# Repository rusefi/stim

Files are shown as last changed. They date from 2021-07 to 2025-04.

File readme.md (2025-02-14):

[Interactive Pinout](https://rusefi.com/docs/pinouts/stim/)

## User Manual

* 12v DC power required
* one microUSB cable required for operation
* sometimes second microUSB is useful for firmware update

WhatsApp Image 2024-11-09 at 19 40 01_332a49eb





* [Download Putty](https://www.chiark.greenend.org.uk/~sgtatham/putty/latest.html)
* bottom microUSB is required for operation
* top microUSB is sometimes needed for firmware updates
* blinking blue LD2 means "alive"
* red LD3 means "board has failed test
* green LD1 next to blinking blue means "test successful"

See https://github.com/rusefi/rusefi-hardware/tree/main/digital-inputs for firmware

Part of https://github.com/rusefi/rusefi infrastucture

https://github.com/rusefi/rusefi/wiki/dev-hardware-quality-control



# Digital Inputs
- 48 channels of high/low digital inputs
- pin requirment: 4 ADC inputs and 9 GPIO

GPIO:
* output: x4 address pins
* output: x4 test control pins
* output: mux off

See https://github.com/rusefi/stim/issues/6

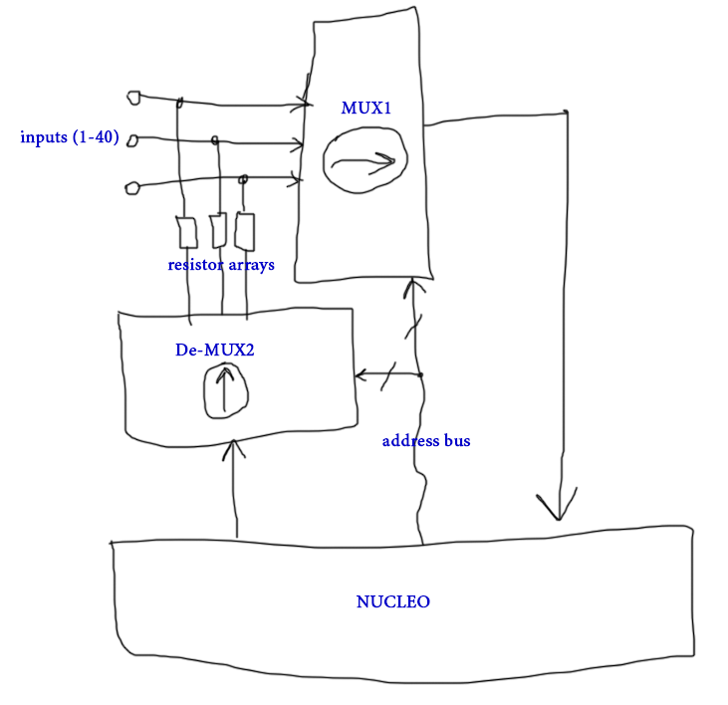
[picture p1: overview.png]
x


# Changelog

## rev C

* CAN board fix
* second CAN board added
* OUT0 pin moved from PA11 to PD8
* https://github.com/rusefi/stim/issues?q=label%3Arev-C+is%3Aclosed

## rev 0.2

* CAN bus
* superseal header

##  rev 0.1
* it works!

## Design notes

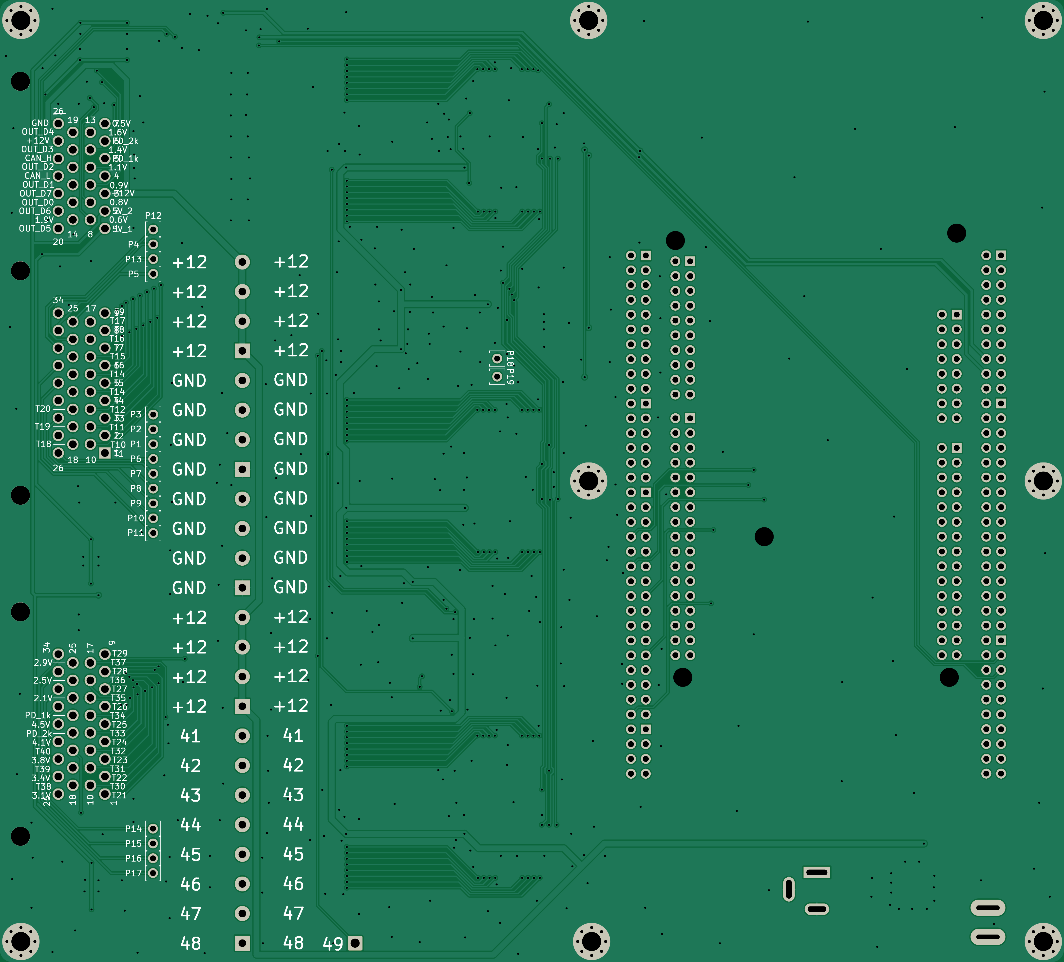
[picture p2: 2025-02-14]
boards/digital_inputs-e/board/misc/digital_inputs-e-bottom.png

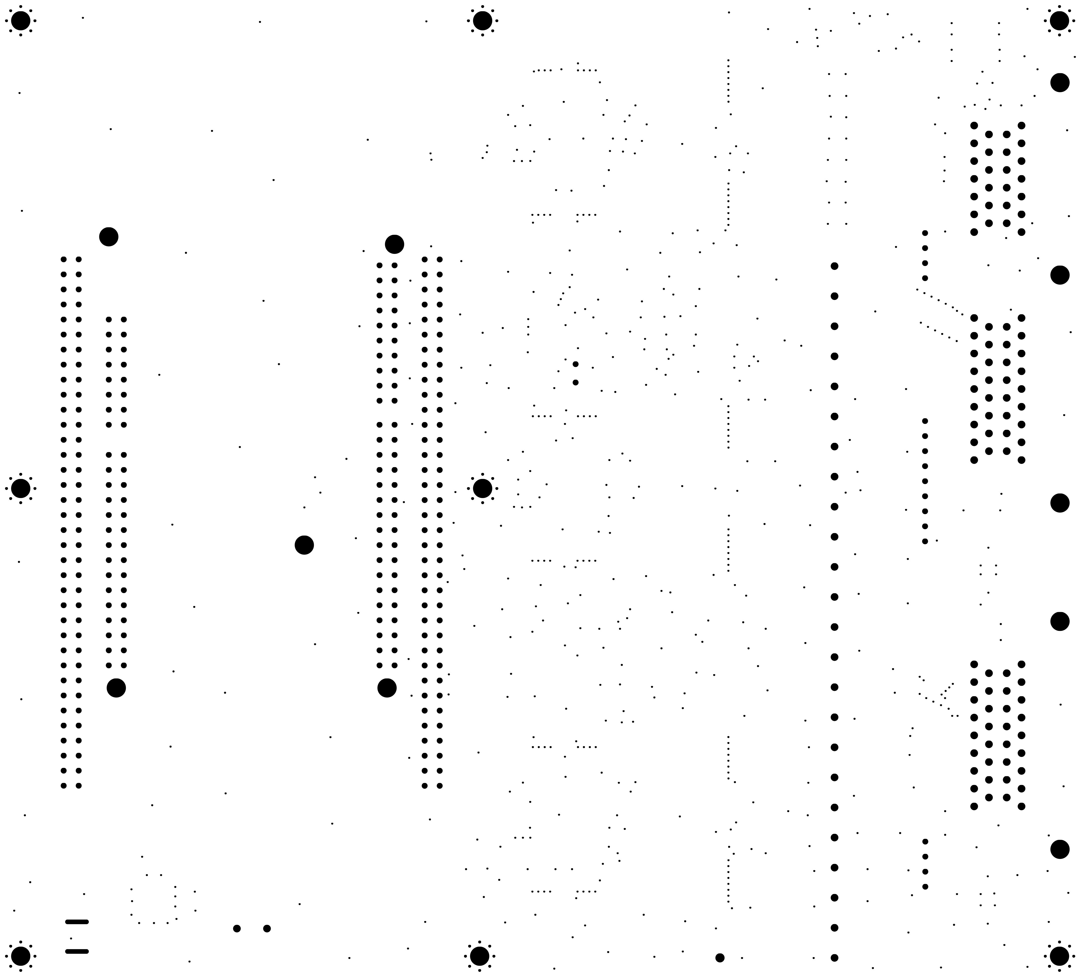
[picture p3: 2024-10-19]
boards/digital_inputs-d/board/misc/digital_inputs-d-outline.png

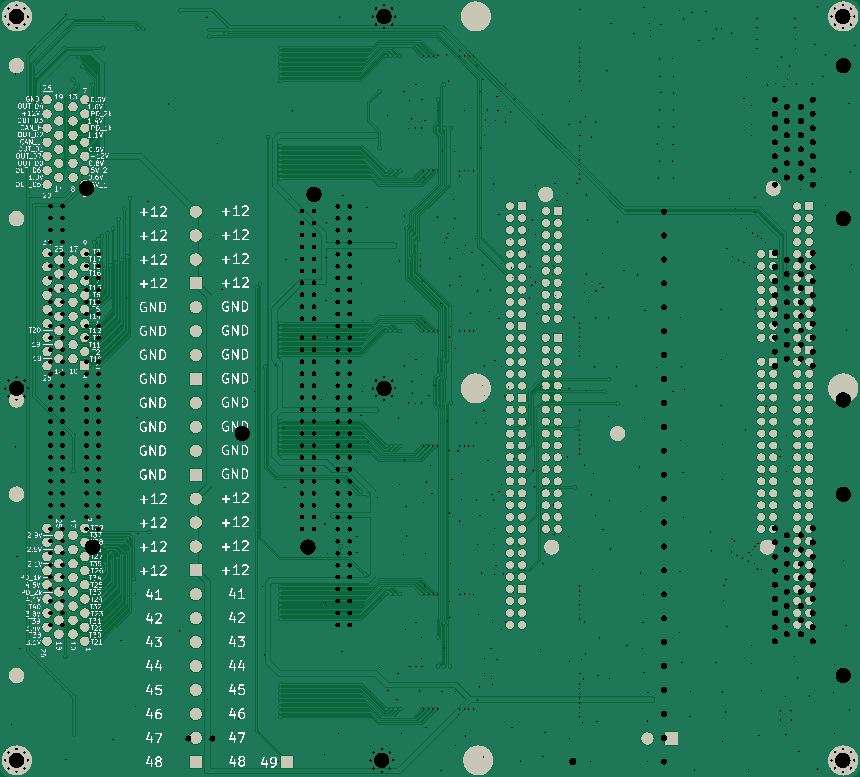
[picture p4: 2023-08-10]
boards/digital_inputs-a/board/misc/digital_inputs-a-bottom.png

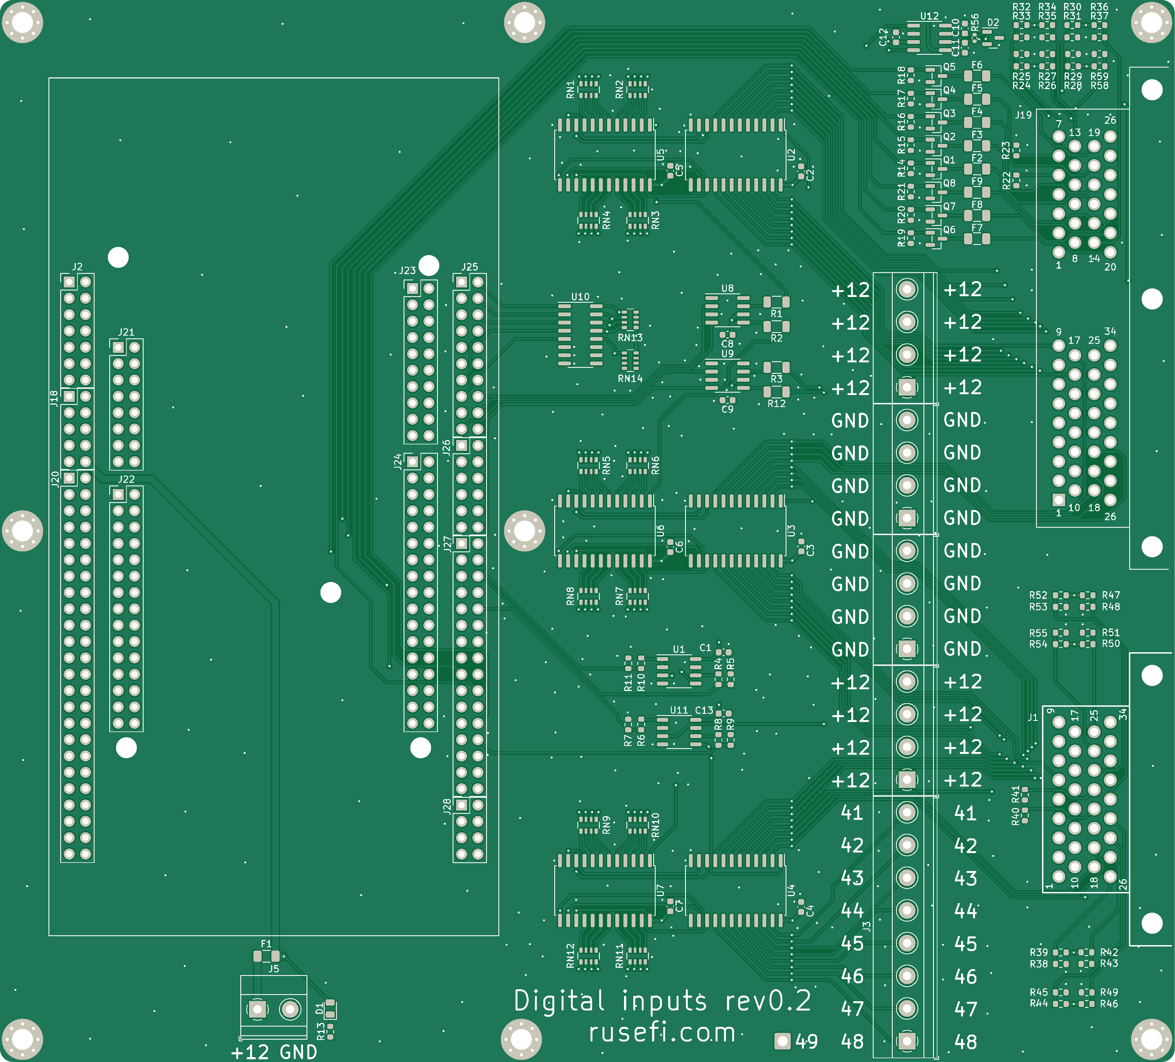
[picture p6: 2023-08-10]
boards/digital_inputs-a/board/digital_inputs-a.png

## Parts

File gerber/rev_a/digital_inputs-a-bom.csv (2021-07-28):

Comment | Designator | Footprint | LCSC Part #
100n | C1 | Capacitor_SMD:C_0603_1608Metric | C14663
100n | C2 | Capacitor_SMD:C_0603_1608Metric | C14663
100n | C3 | Capacitor_SMD:C_0603_1608Metric | C14663
100n | C4 | Capacitor_SMD:C_0603_1608Metric | C14663
100n | C5 | Capacitor_SMD:C_0603_1608Metric | C14663
100n | C6 | Capacitor_SMD:C_0603_1608Metric | C14663
100n | C7 | Capacitor_SMD:C_0603_1608Metric | C14663
100n | C8 | Capacitor_SMD:C_0603_1608Metric | C14663
100n | C9 | Capacitor_SMD:C_0603_1608Metric | C14663
LED | D1 | LED_SMD:LED_0805_2012Metric | C2297
1.8A | F1 | Fuse:Fuse_1206_3216Metric | C369161
Conn_01x16 | J1 | TerminalBlock_Phoenix:TerminalBlock_Phoenix_MKDS-1,5-16-5.08_1x16_P5.08mm_Horizontal
Conn_01x16 | J2 | TerminalBlock_Phoenix:TerminalBlock_Phoenix_MKDS-1,5-16-5.08_1x16_P5.08mm_Horizontal
Conn_01x16 | J3 | TerminalBlock_Phoenix:TerminalBlock_Phoenix_MKDS-1,5-16-5.08_1x16_P5.08mm_Horizontal
Conn_01x01 | J4 | Connector_Wire:SolderWire-0.75sqmm_1x01_D1.25mm_OD2.3mm
Conn_01x02 | J5 | TerminalBlock_Phoenix:TerminalBlock_Phoenix_MKDS-1,5-2-5.08_1x02_P5.08mm_Horizontal
Conn_01x04 | J6 | TerminalBlock_Phoenix:TerminalBlock_Phoenix_MKDS-1,5-4-5.08_1x04_P5.08mm_Horizontal
Conn_01x04 | J7 | TerminalBlock_Phoenix:TerminalBlock_Phoenix_MKDS-1,5-4-5.08_1x04_P5.08mm_Horizontal
Conn_01x04 | J8 | TerminalBlock_Phoenix:TerminalBlock_Phoenix_MKDS-1,5-4-5.08_1x04_P5.08mm_Horizontal
Conn_01x04 | J9 | TerminalBlock_Phoenix:TerminalBlock_Phoenix_MKDS-1,5-4-5.08_1x04_P5.08mm_Horizontal
Conn_01x01 | J10 | MountingHole:MountingHole_3.2mm_M3_Pad_Via
Conn_01x01 | J11 | MountingHole:MountingHole_3.2mm_M3_Pad_Via
Conn_01x01 | J12 | MountingHole:MountingHole_3.2mm_M3_Pad_Via
Conn_01x01 | J13 | MountingHole:MountingHole_3.2mm_M3_Pad_Via
Conn_01x01 | J14 | MountingHole:MountingHole_3.2mm_M3_Pad_Via
Conn_01x01 | J15 | MountingHole:MountingHole_3.2mm_M3_Pad_Via
Conn_01x01 | J16 | MountingHole:MountingHole_3.2mm_M3_Pad_Via
Conn_01x01 | J17 | MountingHole:MountingHole_3.2mm_M3_Pad_Via
1.2k | R1 | Resistor_SMD:R_1206_3216Metric | C26035
1.2k | R2 | Resistor_SMD:R_1206_3216Metric | C26035
1.2k | R3 | Resistor_SMD:R_1206_3216Metric | C26035
4.7k | R4 | Resistor_SMD:R_0603_1608Metric | C23162
1.5k | R5 | Resistor_SMD:R_0603_1608Metric | C22843
4.7k | R6 | Resistor_SMD:R_0603_1608Metric | C23162
1.5k | R7 | Resistor_SMD:R_0603_1608Metric | C22843
4.7k | R8 | Resistor_SMD:R_0603_1608Metric | C23162
1.5k | R9 | Resistor_SMD:R_0603_1608Metric | C22843
4.7k | R10 | Resistor_SMD:R_0603_1608Metric | C23162
1.5k | R11 | Resistor_SMD:R_0603_1608Metric | C22843
1.2k | R12 | Resistor_SMD:R_1206_3216Metric | C26035
4.7k | R13 | Resistor_SMD:R_0603_1608Metric | C23162
0 | RN1 | Resistor_SMD:R_Array_Convex_4x0603 | C327053
0 | RN2 | Resistor_SMD:R_Array_Convex_4x0603 | C327053
0 | RN3 | Resistor_SMD:R_Array_Convex_4x0603 | C327053
0 | RN4 | Resistor_SMD:R_Array_Convex_4x0603 | C327053
0 | RN5 | Resistor_SMD:R_Array_Convex_4x0603 | C327053
0 | RN6 | Resistor_SMD:R_Array_Convex_4x0603 | C327053
0 | RN7 | Resistor_SMD:R_Array_Convex_4x0603 | C327053
0 | RN8 | Resistor_SMD:R_Array_Convex_4x0603 | C327053
0 | RN9 | Resistor_SMD:R_Array_Convex_4x0603 | C327053
0 | RN10 | Resistor_SMD:R_Array_Convex_4x0603 | C327053
0 | RN11 | Resistor_SMD:R_Array_Convex_4x0603 | C327053
0 | RN12 | Resistor_SMD:R_Array_Convex_4x0603 | C327053
10k | RN13 | Resistor_SMD:R_Array_Convex_4x0603 | C29718
10k | RN14 | Resistor_SMD:R_Array_Convex_4x0603 | C29718
OPA4192IPW | U1 | Package_SO:TSSOP-14_4.4x5mm_P0.65mm | C181634
CD4067BM96 | U2 | Package_SO:SOIC-24W_7.5x15.4mm_P1.27mm | C6525
CD4067BM96 | U3 | Package_SO:SOIC-24W_7.5x15.4mm_P1.27mm | C6525
CD4067BM96 | U4 | Package_SO:SOIC-24W_7.5x15.4mm_P1.27mm | C6525
CD4067BM96 | U5 | Package_SO:SOIC-24W_7.5x15.4mm_P1.27mm | C6525
CD4067BM96 | U6 | Package_SO:SOIC-24W_7.5x15.4mm_P1.27mm | C6525
CD4067BM96 | U7 | Package_SO:SOIC-24W_7.5x15.4mm_P1.27mm | C6525
TC4427 | U8 | Package_SO:SOIC-8_3.9x4.9mm_P1.27mm | C20551
TC4427 | U9 | Package_SO:SOIC-8_3.9x4.9mm_P1.27mm | C20551
ULN2003A | U10 | Package_SO:SOIC-16_3.9x9.9mm_P1.27mm | C7512
NUCLEO-F429ZI | U11 | lib:MODULE_NUCLEO-F429ZI

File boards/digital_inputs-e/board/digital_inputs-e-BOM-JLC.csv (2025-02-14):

Comment | Designator | Footprint | LCSC Part #
100n | C1, C2, C3, C4, C5, C6, C7, C8, C9, C12, C13, C16 | C0603 | C14663
47p | C10, C11, C14, C15 | C0603 | C1671
10u | C17, C18 | C0805 | C15850
CircuitBreaker_1P | CB1 | RS601HL-1010011BB | C2885782
LED | D1 | LED_0805_2012Metric | C2297
PESD1CAN | D2, D6 | SOT-23 | C343993
LED-RED-0603 | D3, D4 | LED-0603 | C2286
Barrel_Jack_Switch | J2 | BarrelJack_GCT_DCJ200-10-A_Horizontal | C111567
6437288-3 | J19 | TE_6437288-3 | C591769
Conn_02x10_Odd_Even | J20, J25, J29 | PinHeader_2x10_P2.54mm_Vertical | C92266
Conn_02x16_Odd_Even | J27 | PinHeader_2x16_P2.54mm_Vertical | C132130
AO3400A | Q1, Q2, Q3, Q4, Q5, Q6, Q7, Q8 | SOT-23 | C20917
1.2k | R1, R2, R3, R12 | R1206 | C26035
4.7k | R4, R6, R8, R10, R14, R15, R16, R17, R18, R19, R20, R21, R57, R60 | R0603 | C23162
1.5k | R5, R7, R9, R11 | R0603 | C22843
13k | R13 | R0603 | C22797
1k | R22, R40 | R0603 | C21190
2k | R23, R41 | R0603 | C4190
820 | R24, R26, R30, R32, R36, R39, R49 | R0603 | C23253
100 | R25, R29, R44, R46, R47, R59 | R0603 | C22775
120 | R27 | R0603 | C22787
470 | R28, R34, R43, R51, R52, R54, R55 | R0603 | C23179
220 | R31, R35, R42 | R0603 | C22962
330 | R33, R45, R50, R53 | R0603 | C23138
510 | R37, R38, R58 | R0603 | C23193
910 | R48 | R0603 | C23264
0 | RN1, RN2, RN3, RN4, RN5, RN6, RN7, RN8, RN9, RN10, RN11, RN12 | R_Array_Convex_4x0603 | C327053
10k | RN13, RN14 | R_Array_Convex_4x0603 | C29718
OPA2192IDR | U1, U11 | SO-8_3.9x4.9mm_P1.27mm | C110074
CD4067BM96 | U2, U3, U4, U5, U6, U7 | SOIC-24W_7.5x15.4mm_P1.27mm | C6525
TC4427 | U8, U9 | SO8 | C20551
ULN2003A | U10 | SOIC-16_3.9x9.9mm_P1.27mm | C7512
TJA1051T-3 | U12, U13 | SO8 | C38695
LM78M05_TO252 | U14 | DPAK | C58069
nSMD005 | F2, F3, F4, F5, F6, F7, F8, F9 | F1206 | C70064
nSMD100-16 | F1 | F1206 | C70082

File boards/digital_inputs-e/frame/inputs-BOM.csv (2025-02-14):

Comment | Designator | Footprint | LCSC Part #
100n | C1 | C0603 | C14663
100n | C2 | C0603 | C14663
100n | C3 | C0603 | C14663
100n | C4 | C0603 | C14663
100n | C5 | C0603 | C14663
100n | C6 | C0603 | C14663
100n | C7 | C0603 | C14663
100n | C8 | C0603 | C14663
100n | C9 | C0603 | C14663
47p | C10 | C0603 | C1671
47p | C11 | C0603 | C1671
100n | C12 | C0603 | C14663
100n | C13 | C0603 | C14663
47p | C14 | C0603 | C1671
47p | C15 | C0603 | C1671
100n | C16 | C0603 | C14663
10u | C17 | C0805 | C15850
10u | C18 | C0805 | C15850
CircuitBreaker_1P | CB1 | RS601HL-1010011BB | C2885782
LED | D1 | LED_0805_2012Metric | C2297
PESD1CAN | D2 | SOT-23 | C343993
LED-RED-0603 | D3 | LED-0603 | C2286
LED-RED-0603 | D4 | LED-0603 | C2286
PESD1CAN | D6 | SOT-23 | C343993
1.8A | F1 | Fuse_1206_3216Metric | C369161
nSMD005 | F2 | Fuse_1206_3216Metric | C369153
nSMD005 | F3 | Fuse_1206_3216Metric | C369153
nSMD005 | F4 | Fuse_1206_3216Metric | C369153
nSMD005 | F5 | Fuse_1206_3216Metric | C369153
nSMD005 | F6 | Fuse_1206_3216Metric | C369153
nSMD005 | F7 | Fuse_1206_3216Metric | C369153
nSMD005 | F8 | Fuse_1206_3216Metric | C369153
nSMD005 | F9 | Fuse_1206_3216Metric | C369153
MountingHole | H1 | MountingHole_3.2mm_M3
MountingHole | H2 | MountingHole_3.2mm_M3
MountingHole | H3 | MountingHole_3.2mm_M3
MountingHole | H4 | MountingHole_3.2mm_M3
MountingHole | H5 | MountingHole_3.2mm_M3
6437288-2 | J1 | 6437288-2
Barrel_Jack_Switch | J2 | BarrelJack_GCT_DCJ200-10-A_Horizontal | C111567
Conn_01x08 | J3 | TerminalBlock_Phoenix_MKDS-1,5-8-5.08_1x08_P5.08mm_Horizontal
Conn_01x01 | J4 | SolderWire-0.75sqmm_1x01_D1.25mm_OD2.3mm
Conn_01x04 | J6 | TerminalBlock_Phoenix_MKDS-1,5-4-5.08_1x04_P5.08mm_Horizontal
Conn_01x04 | J7 | TerminalBlock_Phoenix_MKDS-1,5-4-5.08_1x04_P5.08mm_Horizontal
Conn_01x04 | J8 | TerminalBlock_Phoenix_MKDS-1,5-4-5.08_1x04_P5.08mm_Horizontal
Conn_01x04 | J9 | TerminalBlock_Phoenix_MKDS-1,5-4-5.08_1x04_P5.08mm_Horizontal
Conn_01x01 | J10 | MountingHole_3.2mm_M3_Pad_Via
Conn_01x01 | J11 | MountingHole_3.2mm_M3_Pad_Via
Conn_01x01 | J12 | MountingHole_3.2mm_M3_Pad_Via
Conn_01x01 | J13 | MountingHole_3.2mm_M3_Pad_Via
Conn_01x01 | J14 | MountingHole_3.2mm_M3_Pad_Via
Conn_01x01 | J15 | MountingHole_3.2mm_M3_Pad_Via
Conn_01x01 | J16 | MountingHole_3.2mm_M3_Pad_Via
Conn_01x01 | J17 | MountingHole_3.2mm_M3_Pad_Via
6437288-3 | J19 | TE_6437288-3 | C591769
Conn_02x10_Odd_Even | J20 | PinHeader_2x10_P2.54mm_Vertical | C92266
Conn_02x08_Odd_Even | J21 | PinHeader_2x08_P2.54mm_Vertical
Conn_02x15_Odd_Even | J22 | PinHeader_2x15_P2.54mm_Vertical
Conn_02x10_Odd_Even | J23 | PinHeader_2x10_P2.54mm_Vertical
Conn_02x17_Odd_Even | J24 | PinHeader_2x17_P2.54mm_Vertical
Conn_02x10_Odd_Even | J25 | PinHeader_2x10_P2.54mm_Vertical | C92266
Conn_02x06_Odd_Even | J26 | PinHeader_2x06_P2.54mm_Vertical
Conn_02x16_Odd_Even | J27 | PinHeader_2x16_P2.54mm_Vertical | C132130
Conn_02x04_Odd_Even | J28 | PinHeader_2x04_P2.54mm_Vertical
Conn_02x10_Odd_Even | J29 | PinHeader_2x10_P2.54mm_Vertical | C92266
Conn_02x14_Odd_Even | J30 | PinHeader_2x16_P2.54mm_Vertical
Pad | P1 | PAD-TH
Pad | P2 | PAD-TH
Pad | P3 | PAD-TH
Pad | P4 | PAD-TH
Pad | P5 | PAD-TH
Pad | P6 | PAD-TH
Pad | P7 | PAD-TH
Pad | P8 | PAD-TH
Pad | P9 | PAD-TH
Pad | P10 | PAD-TH
Pad | P11 | PAD-TH
Pad | P12 | PAD-TH
Pad | P13 | PAD-TH
Pad | P14 | PAD-TH
Pad | P15 | PAD-TH
Pad | P16 | PAD-TH
Pad | P17 | PAD-TH
Pad | P18 | PAD-TH
Pad | P19 | PAD-TH
AO3400A | Q1 | SOT-23 | C20917
AO3400A | Q2 | SOT-23 | C20917
AO3400A | Q3 | SOT-23 | C20917
AO3400A | Q4 | SOT-23 | C20917
AO3400A | Q5 | SOT-23 | C20917
AO3400A | Q6 | SOT-23 | C20917
AO3400A | Q7 | SOT-23 | C20917
AO3400A | Q8 | SOT-23 | C20917
1.2k | R1 | R1206 | C26035
1.2k | R2 | R1206 | C26035
1.2k | R3 | R1206 | C26035
4.7k | R4 | R0603 | C23162
1.5k | R5 | R0603 | C22843
4.7k | R6 | R0603 | C23162
1.5k | R7 | R0603 | C22843
4.7k | R8 | R0603 | C23162
1.5k | R9 | R0603 | C22843
4.7k | R10 | R0603 | C23162
1.5k | R11 | R0603 | C22843
1.2k | R12 | R1206 | C26035
13k | R13 | R0603 | C22797
4.7k | R14 | R0603 | C23162
4.7k | R15 | R0603 | C23162
4.7k | R16 | R0603 | C23162
4.7k | R17 | R0603 | C23162
4.7k | R18 | R0603 | C23162
4.7k | R19 | R0603 | C23162
4.7k | R20 | R0603 | C23162
4.7k | R21 | R0603 | C23162
1k | R22 | R0603 | C21190
2k | R23 | R0603 | C4190
820 | R24 | R0603 | C23253
100 | R25 | R0603 | C22775
820 | R26 | R0603 | C23253
120 | R27 | R0603 | C22787
470 | R28 | R0603 | C23179
100 | R29 | R0603 | C22775
820 | R30 | R0603 | C23253
220 | R31 | R0603 | C22962
820 | R32 | R0603 | C23253
330 | R33 | R0603 | C23138
470 | R34 | R0603 | C23179
220 | R35 | R0603 | C22962
820 | R36 | R0603 | C23253
510 | R37 | R0603 | C23193
510 | R38 | R0603 | C23193
820 | R39 | R0603 | C23253
1k | R40 | R0603 | C21190
2k | R41 | R0603 | C4190
220 | R42 | R0603 | C22962
470 | R43 | R0603 | C23179
100 | R44 | R0603 | C22775
330 | R45 | R0603 | C23138
100 | R46 | R0603 | C22775
100 | R47 | R0603 | C22775
910 | R48 | R0603 | C23264
820 | R49 | R0603 | C23253
330 | R50 | R0603 | C23138
470 | R51 | R0603 | C23179
470 | R52 | R0603 | C23179
330 | R53 | R0603 | C23138
470 | R54 | R0603 | C23179
470 | R55 | R0603 | C23179
DNP | R56 | R0603
4.7k | R57 | R0603 | C23162
510 | R58 | R0603 | C23193
100 | R59 | R0603 | C22775
4.7k | R60 | R0603 | C23162
DNP | R62 | R0603
0 | RN1 | R_Array_Convex_4x0603 | C327053
0 | RN2 | R_Array_Convex_4x0603 | C327053
0 | RN3 | R_Array_Convex_4x0603 | C327053
0 | RN4 | R_Array_Convex_4x0603 | C327053
0 | RN5 | R_Array_Convex_4x0603 | C327053
0 | RN6 | R_Array_Convex_4x0603 | C327053
0 | RN7 | R_Array_Convex_4x0603 | C327053
0 | RN8 | R_Array_Convex_4x0603 | C327053
0 | RN9 | R_Array_Convex_4x0603 | C327053
0 | RN10 | R_Array_Convex_4x0603 | C327053
0 | RN11 | R_Array_Convex_4x0603 | C327053
0 | RN12 | R_Array_Convex_4x0603 | C327053
10k | RN13 | R_Array_Convex_4x0603 | C29718
10k | RN14 | R_Array_Convex_4x0603 | C29718
OPA2192IDR | U1 | SO-8_3.9x4.9mm_P1.27mm | C110074
CD4067BM96 | U2 | SOIC-24W_7.5x15.4mm_P1.27mm | C6525
CD4067BM96 | U3 | SOIC-24W_7.5x15.4mm_P1.27mm | C6525
CD4067BM96 | U4 | SOIC-24W_7.5x15.4mm_P1.27mm | C6525
CD4067BM96 | U5 | SOIC-24W_7.5x15.4mm_P1.27mm | C6525
CD4067BM96 | U6 | SOIC-24W_7.5x15.4mm_P1.27mm | C6525
CD4067BM96 | U7 | SOIC-24W_7.5x15.4mm_P1.27mm | C6525
TC4427 | U8 | SO8 | C20551
TC4427 | U9 | SO8 | C20551
ULN2003A | U10 | SOIC-16_3.9x9.9mm_P1.27mm | C7512
OPA2192IDR | U11 | SO-8_3.9x4.9mm_P1.27mm | C110074
TJA1051T-3 | U12 | SO8 | C38695
TJA1051T-3 | U13 | SO8 | C38695
LM78M05_TO252 | U14 | DPAK | C58069

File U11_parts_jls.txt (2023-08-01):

C92264 DS1023-2*17SF11
C92264 DS1023-2*17SF11

C92267 DS1023-2*8SF11
C132129 DS1023-2*15SF11

C92266 DS1023-2*10SF11
C92264 DS1023-2*17SF11

C92266 DS1023-2*10SF11
C92266 DS1023-2*10SF11
C132127 DS1023-2*13SF11

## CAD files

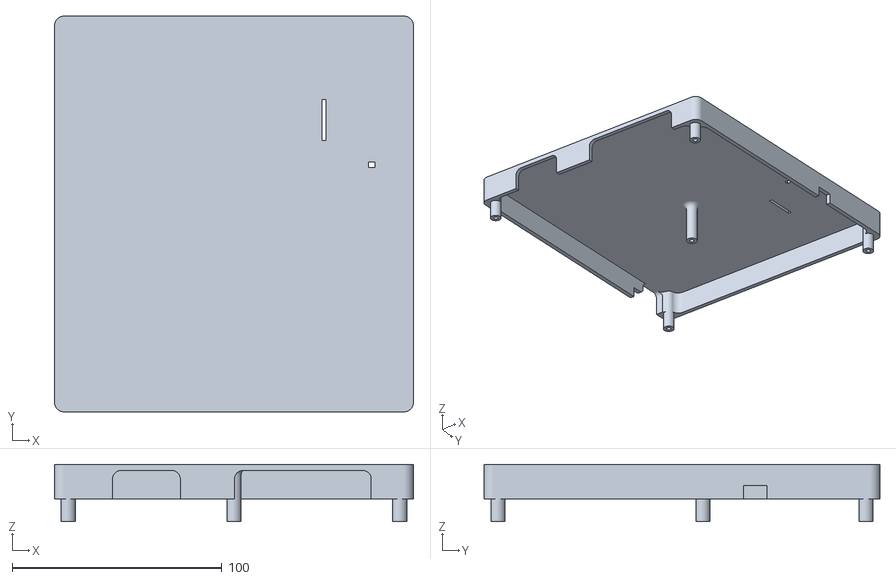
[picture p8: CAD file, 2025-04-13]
enclosure/IWS Top Case.stl
171.0 x 188.5 x 27.2

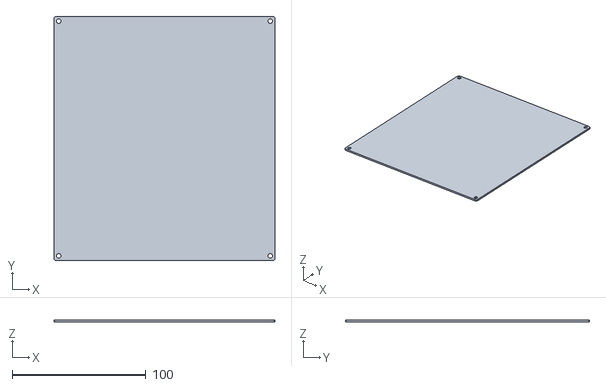
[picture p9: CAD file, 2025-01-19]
enclosure/v1/BottomPiece-TestRig.stl
165.0 x 182.5 x 1.63

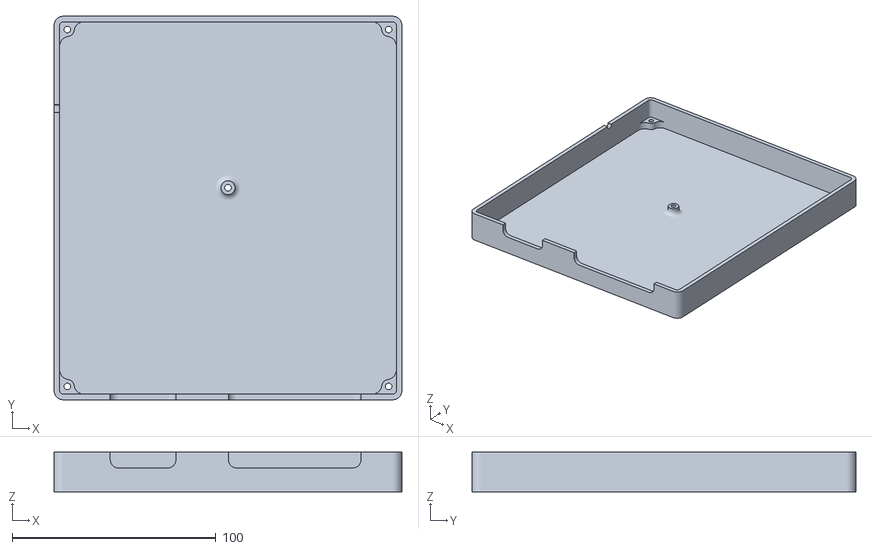
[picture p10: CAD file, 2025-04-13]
enclosure/IWS Bottom Case.stl
171.0 x 188.5 x 19.5

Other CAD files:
enclosure/v1/Top Case-testrig.stl

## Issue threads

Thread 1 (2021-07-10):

5v to 10-18v voltage raising power supply

rusefillc, 2021-07-10:
Can we take +5v from USB and make somewhere from 10 to 18 volts out of it? this would eliminate need of wall power supply and increase overall usability

mck1117, 2021-07-10:
There's a catch I didn't think of - if we want to actually test injector drivers with 1-2 amps, this won't work.

rusefillc, 2021-07-10:
would we need 1a to validate soldering on low side dricers?

Closed 2023-07-27.

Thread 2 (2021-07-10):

Slow Analog Stim module

rusefillc, 2021-07-10:
We need a module to stimulate up to XXX 0-5v analog channels. ECU could have 1K or more pull-up/down.

rusefillc, 2021-07-10:
Would an SPI DAC be the way to go? Does JLC have any? Would SPI DAC produce current needed to accommodate for instance 1K pull-down?

stefanst, 2021-07-10:
MCP4726 DAC is available on JLC.
But addressing become a problem.
Maybe just use one DAC and analog switches?

mck1117, 2021-07-10:
BH2226F-E2 looks great but isn't JLC, plus it's only $2 each, and easy to solder by hand.  Doing a few of those wouldn't be bad at all.

stefanst, 2021-07-10:
No stock of BH2226F-E2 at Mouser or Digikey
BH2221FV-E2 with 12 channels seems available though.

andreika-git, 2021-07-10:
We don't need all analog channels at the same time. We could do the same trick with a multichannel analog demux (see #6), opamp and only 1 DAC output (nucleo already has it).

rusefillc, 2023-07-27:
only static analog pins for now

Closed 2023-07-27.

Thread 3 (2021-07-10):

Hall sensor / digital switch stim

rusefillc, 2021-07-10:
we need up to eight channels of Hall / switch stimulation

stefanst, 2021-07-10:
Hall should be easy- just an NPN transistor.

rusefillc, 2021-07-10:
but we need 16 of these so some muxing?

stefanst, 2021-07-10:
If memory serves right, more like de-muxing. But yes.

mck1117, 2021-07-10:
or not - just use a 208 pin mcu

rusefillc, 2021-07-10:
208 pin MCU does not exist in 2021.
only 144 pin MCU exist unless you give me available part numbers for Nucleo 176 or else :)

rusefillc, 2023-07-23:
firmware side https://github.com/rusefi/rusefi-hardware/issues/222

next step: selecting eight pins on 144 pin STM32 Nucleo-F429ZI which we can toggle without any interference from other hardware on STM32 Nucleo-F429ZI and not yet used by existing https://github.com/rusefi/rusefi-hardware/tree/main/digital-inputs

rusefillc, 2023-07-26:
CN1-2 would be most convenient
CN1-1 second most convenient

но можно любые

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

andreika-git, 2023-07-26:
Let's use these 8 pins on the CN12 connector:

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

PE0, PE7-13.

rusefillc, 2023-07-26:
@Qwerty-OFF сделай пожалуйста схематику одного вывода для тестирования цифрового датчика на пине PE0?

Qwerty-OFF, 2023-07-26:
Сделал
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

Nadezhda-n, 2023-07-27:
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
OUT_HALO_* на  любые ноги 6437288-3?

rusefillc, 2023-07-27:
@Nadezhda-n https://rusefi.com/docs/pinouts/stim/?connector=main&pin=15B и так далее, что digital out - не только hall

Nadezhda-n, 2023-07-27:
> @Nadezhda-n https://rusefi.com/docs/pinouts/stim/?connector=main&pin=15B и так далее, что digital out - не только hall

что

Nadezhda-n, 2023-07-27:
Есть 4 out на NUCLEO-F429ZI, а также 8 hallo
А на разъеме 8 digital out

Nadezhda-n, 2023-07-28:
Теперь я понимаю, что digital out как раз для этих hallo

Closed 2023-08-02.

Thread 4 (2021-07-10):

Analog Sensing Board

rusefillc, 2021-07-10:
we need 3v SPI chainable 16 channel 5v ADC board
could be any number of chips but lower is better to reduce CS lines?

rusefillc, 2021-07-10:
board should have optional pull-ups/pull-downs allowing low side drive sensing, i.e. testing of injector drivers etc

mck1117, 2021-07-10:
Another option is to use analog switches/muxes and use onboard STM ADC.  One ADC gets us 16 channels, and a bunch of 2x or 4x muxes would get 32 or 64 channels.

rusefillc, 2021-07-10:
But do we even need ADC at all?

#6

Closed 2023-07-27.

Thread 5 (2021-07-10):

Basics

stefanst, 2021-07-10:
Before we start designing circuits, how about a list of requirements?

rusefillc, 2021-07-10:
https://github.com/rusefi/rusefi/wiki/dev-hardware-quality-control#requirements

rusefillc, 2021-07-10:
An interesting thing to approximate would be rate of testing

As is I have no idea what's the time to SEND+ACK a text command via our protocol, and it could be that we would be sending commands to two different devices etc etc.

maybe can between ECU and Stim is really important, that case PC sends Stim one command and Stim exchanges data with ECU directly

stefanst, 2021-07-10:
I don't see rate of test as a real issue
Let's say we have a max. of 120 i/o which seems reasonable. Even if each test takes one full second, it would only be 2 minutes total. Setup time with flashing firmware twice (before and after testing) will take longer than that. So the time bottleneck would be setup time.

stefanst, 2021-07-13:
Most basic configuration:
- 16x digital potentiometer (different values might be helpful)
- 16 digital out for emulating
  - Cam/ Crank sensors
  - Frequency-based sensors
  - switches
- One fake VR output
- 32 digital in for monitoring digital or PWM outputs
- Maybe 8 PWM -> voltage converters (RC) for simple monitoring of PWM outputs?

Closed 2023-07-23.

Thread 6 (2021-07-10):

Digital Outputs Sense

rusefillc, 2021-07-10:
Open question if low/high/H outputs should be verified using ADC or just digitally

since we need at least 32-48 channels it has to a multiplexor setup

maybe three of same PCB for 16 channels each?

rusefillc, 2021-07-10:
H-bridge would have what static pull-up/pull-down? or shall we mux pull-ups/pull-downs?

rusefillc, 2021-07-10:
@andreika-git proposal

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

injector scenario: mux 2 pulls wire up to +3v
12v tach signal scenario:

andreika-git, 2021-07-10:
MUX1 is something like CD4067BM96_C6525 + PCA9538PWR_C201530 + opamp + resistor divider + nucleo_analog_input

rusefillc, 2023-07-27:
This all works now!

Closed 2023-07-27.

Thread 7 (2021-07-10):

Current Sensing

rusefillc, 2021-07-10:
it would be amazing to sense 12v ECU current

rusefillc, 2021-07-10:
https://jlcpcb.com/parts/componentSearch?isSearch=true&searchTxt=C44471 ?

Closed 2023-07-27.

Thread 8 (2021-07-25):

Rename folder and board to digital_inputs

rusefillc, 2021-07-25:
Please rename "stim" folder and files to "digital_inputs"

rusefillc, 2021-07-25:
#6

Qwerty-OFF, 2021-07-25:
Done
New link to schematic:
https://github.com/rusefi/stim/blob/main/digital_inputs/gerber/digital_inputs.pdf

Closed 2021-07-27.

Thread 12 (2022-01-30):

digital inputs: vin +12v would not go well

rusefillc, 2022-01-30:
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

i think Nucleo boards would be very upset by +12v power

rusefillc, 2022-01-30:
i will cut this trace and power brain board externally for now

rusefillc, 2022-10-02:
Actually I could be wrong here?

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

rusefillc, 2022-10-02:
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

Closed 2022-10-02.

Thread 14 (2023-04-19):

60+34 pin superseal 1.0 connectors

rusefillc, 2023-04-19:
let's use 60+34 pin superseal 1.0 connector same as https://github.com/rusefi/alphax-8chan/

Power, CAN and all inputs should be moved to that connectors, current wire provisions are not needed

back side of PCB should have some nice silk please

Nadezhda-n, 2023-05-02:
What are the inputs here? :)

Nadezhda-n, 2023-05-02:
> Sorry outputs @Nadezhda-n

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
?

Nadezhda-n, 2023-05-02:
Плату нужно увеличивать, верно?
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

rusefillc, 2023-07-22:
@rusefillc не совсем - ведь на эти 60 пинов уйдут примерно 36 текущих отверстий справа

48 каналов мне по факту просто не нужно - так что про каналы 33-48 я подумаю чуть позже

а вот 1-32 идут на разъём. Наверное мне стоит сделать картинку желаемой распиновки, и всем станет лучше!

rusefillc, 2023-07-26:
т.е. правый-верхний угол платы заменяется вот на такую распиновку

https://rusefi.com/docs/pinouts/stim/

https://github.com/rusefi/stim/blob/main/digital_inputs/connectors/60pins.yaml

Nadezhda-n, 2023-07-27:
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

Nadezhda-n, 2023-07-27:
Куда подключать out4-out7??
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

Nadezhda-n, 2023-07-31:
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
Такая будет компоновка?
@rusefillc

rusefillc, 2023-07-31:
если 60 пин развернуть на 180 градусов - то да.

rusefillc, 2023-07-31:
> Куда подключать out4-out7??

 out4-out7 это внутренние трассы, идущие на чипы - их не нужно трогать и выводить на разъёмы

Nadezhda-n, 2023-08-01:
Я плату добавила, вроде с меня на данном этапе все.
@rusefillc @Qwerty-OFF

Qwerty-OFF, 2023-08-02:
Подразумевалось что-то типа OUT_HALL0, OUT_HALL1, сейчас названия выглядят немного странно
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

@rusefillc для CAN 120 Ом и защитные диоды нужны?

@rusefillc хочешь ли ты подписи функционала у разъемов с обратной стороны платы или это особый вид наказания специально для меня?

Больше возражений не имею

rusefillc, 2023-08-02:
@Qwerty-OFF спасибо огромное! два тикета сделал

Closed 2023-08-08.

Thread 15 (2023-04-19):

change silk and schematics to rev B

rusefillc, 2023-04-19:
rev B time!

CAN needs to be traced at the moment we only have schematics progress https://github.com/rusefi/stim/issues/13

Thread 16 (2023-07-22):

voltage output for static test of analog inputs

rusefillc, 2023-07-22:
stim board should provide 8 points of reference voltage outputs

8 пар резисторов для делителей - середина делитеря идёт наружу. общая земля.

верхние 5 вольт на первые 4 канала приходят снаружи с пина 2A https://rusefi.com/docs/pinouts//stim/?pin=1B
верхние 5 вольт на вторые 4 канала приходят снаружи с пина 2B

rusefillc, 2023-07-22:
@Qwerty-OFF please provide resistor divider values for us to divide 5v

Qwerty-OFF, 2023-07-24:
|   | Voltage  | R up |  R down |
| - | ----- | ---- | ----- |
| 1 | 0.5v  | 910 | 100 |
| 2 | 0.9v  | 470 | 100 |
| 3 | 1.3v  | 910 | 330 |
| 4 | 1.7v  | 910 | 470 |
| 5 | 2.1v  | 470 | 330 |
| 6 | 2.5v  | 470 | 470 |
| 7 | 2.9v  | 330 | 470 |
| 8 | 3.3v  | 470 | 910 |
| 9 | 3.7v  | 330 | 910 |
| 10 | 4.1v  | 100 | 470 |

Nadezhda-n, 2023-07-27:
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

Nadezhda-n, 2023-07-27:
Extended Part
910
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

rusefillc, 2023-07-27:
@Nadezhda-n любой номинал от 890 до 940

жадность проснулась и просит всё-таки 16 каналов - значит любые 6 пар номиналов будут повторяться два раза https://github.com/rusefi/stim/commit/6b318c73dd3a7ee15cf343e752e1aa83c5f0f26b

Nadezhda-n, 2023-07-28:
> @Nadezhda-n любой номинал от 890 до 940
>
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

Nadezhda-n, 2023-07-28:
> @Nadezhda-n любой номинал от 890 до 940
>

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

Nadezhda-n, 2023-07-28:
> жадность проснулась и просит всё-таки 16 каналов - значит любые 6 пар номиналов будут повторяться два раза [6b318c7](https://github.com/rusefi/stim/commit/6b318c73dd3a7ee15cf343e752e1aa83c5f0f26b)

С этим набором может быть 13 разных значений, тебе действительно нужны 16?

Nadezhda-n, 2023-07-28:
> @Nadezhda-n любой номинал от 890 до 940
>
> жадность проснулась и просит всё-таки 16 каналов - значит любые 6 пар номиналов будут повторяться два раза [6b318c7](https://github.com/rusefi/stim/commit/6b318c73dd3a7ee15cf343e752e1aa83c5f0f26b)

И как расставлять 5В?
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

Nadezhda-n, 2023-08-01:
REF14-16 удаляем?

rusefillc, 2023-08-01:
> REF14-16 удаляем?

не понимаю, почему удаляем? они же есть на распиновке? https://rusefi.com/docs/pinouts/stim/?pin=30C

rusefillc, 2023-08-01:
> REF14-16 удаляем?

примерно любые пары резисторов из набора Володиного

Nadezhda-n, 2023-08-01:
> И как расставлять 5В?

по 4 на каждые у обоих разъемов или на один разъем 5V_1, а на другой 5V_2?

Qwerty-OFF, 2023-08-02:
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
В группах вероятно неразличимы между собой будут REF3 и REF4, REF7 и REF8, если это важно

rusefillc, 2023-08-02:
> 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 В группах вероятно неразличимы между собой будут REF3 и REF4, REF7 и REF8, если это важно

ref4 насколько тревиально поднять до 1.4v? ещё есть вариант резисторы поставить 1% - эта плата достаточно важна для этого

@Qwerty-OFF давай поставим резисторы 1% и попробуем вообще улучшить, если малыми усилиями

Qwerty-OFF, 2023-08-02:
@Nadezhda-n ты сможешь выдумать 16 пар резисторов 1% любого номинала какой найдешь на JLC? Так чтобы:
- все соседние напряжение отличались хотя бы на 10%
- сумма резисторов была 500-1500 Ом

Можно ориентироваться на такой ряд напряжений
4.25
3.61
3.07
2.61
2.22
1.89
1.60
1.36
1.16
0.98
0.84
0.71
0.60
0.51
0.44
0.37

rusefillc, 2023-08-02:
> @Nadezhda-n ты сможешь выдумать 16 пар резисторов 1% любого номинала

если за 30 минут не найдётся, я бы просто бы нашёл 1% резисторы как они есть. вроде у нас АЦП всё-таки 10 бит и модные опорные 5 вольт?

Nadezhda-n, 2023-08-02:
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
Вот что получилось

Nadezhda-n, 2023-08-02:
линейка резисторов в омах
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

Qwerty-OFF, 2023-08-02:
В 10% кажется в нескольких местах не попадает (если посчитать напряжения с десятыми), но 5% есть. Думаю можно так оставить.

Closed 2023-08-08.

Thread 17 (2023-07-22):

pull-down outputs for static test of analog inputs

rusefillc, 2023-07-22:
1K pull-down https://rusefi.com/docs/pinouts/stim/?pin=5B
2K pull-down https://rusefi.com/docs/pinouts/stim/?pin=6B

Nadezhda-n, 2023-07-27:
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

rusefillc, 2023-07-27:
жадность подумала и попросила ещё два аналогичных канала ещё два резистора см. https://github.com/rusefi/stim/commit/88509c994097df87f4fc304cbd68412635387c8c

Nadezhda-n, 2023-07-28:
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

Qwerty-OFF, 2023-08-02:
Выглядит хорошо

Closed 2023-08-02.

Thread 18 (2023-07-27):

let's have china solder CN1-2

rusefillc, 2023-07-27:
let's add part numbers for "x by 2" headers for JLC to solder so that I can just hook nucleo board to stim board

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

rusefillc, 2023-07-31:
если у JLC нет идеальных разъёмов - давайте обсудим, насколько будет просто запаять хотя бы частичный разъём - может быть скобинировать из нескольких разъёмов с пропусками

сейчас добавлю картинку, чтоб повысить шанс меня понять

rusefillc, 2023-07-31:
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

rusefillc, 2023-08-01:
> Я не знаю, кто такие "x by 2" headers

я про разъёмы на U11, там 6 штук разного размера например 8x2 и 10x2 и ещё какие-то более длинные

Nadezhda-n, 2023-08-01:
> > Я не знаю, кто такие "x by 2" headers
>
> я про разъёмы на U11, там 6 штук разного размера например 8x2 и 10x2 и ещё какие-то более длинные

Вместо U11 стоят разъемы 2,54 стандартные и нужно подобрать перечень с jls, чтобы поставиьь их во все отверстия футпринта?

rusefillc, 2023-08-01:
@Nadezhda-n на 90% да!

если всё легко и у них есть все разъёмы - то просто ставим

нюансы
* если какой-то разъём у нас не испольщуется вообще - аргумент не ставить, чтоб проще было вставлять-вынимать U11
* если правильных огромных у JLC нет, то большую серцию есть идея разделить логически и попросить JLC напаять хотя бы самые важные для нас сектора

Nadezhda-n, 2023-08-01:
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

В первой линии у нас используется 5 пинов, то есть можно взять PLD-10 или нужно побольше? (Кстати, вилки нужны?)

Nadezhda-n, 2023-08-01:
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
C92264 DS1023-2*17SF11
C92264 DS1023-2*17SF11

C92267 DS1023-2*8SF11
C132129 DS1023-2*15SF11

C92266 DS1023-2*10SF11
C92264 DS1023-2*17SF11

C92266 DS1023-2*10SF11
C92266 DS1023-2*10SF11
C132127 DS1023-2*13SF11

Qwerty-OFF, 2023-08-02:
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

Nadezhda-n, 2023-08-02:
> 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

Суть в том, что корпус разъема немного больше (0,5+-0,3мм), и вот вплотную три подряд разъема могут не влезть, поэтому может все таки сделаем с зазорами, как я кидала выше?

Qwerty-OFF, 2023-08-02:
Соседние разъемы не будут паяться, я в BOM поставил только те, что нужны

Closed 2023-08-08.

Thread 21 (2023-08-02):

board export fails due to missing aux_axis_origin

rusefillc, 2023-08-02:
looks like PCB does not have "aux_axis_origin" whatever that is, as a result automation fails

Closed 2023-08-02.

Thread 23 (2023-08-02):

шёлкография разъёмов сзади

rusefillc, 2023-08-02:

Nadezhda-n, 2023-08-02:
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
так подойдет?
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
Чтобы путаницы с номерами не было, эти пины начинала с буквы Т, REF записала числовыми значениями, HALL как OUT_D0-7
@Qwerty-OFF

rusefillc, 2023-08-02:
@Nadezhda-n красота!

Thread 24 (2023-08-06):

manually fix units (at least in drill files)

rusefillc, 2023-08-06:
Automations is failing because of mm<>inches wrong setting

See https://github.com/andreika-git/hellen-one/issues/320

rusefillc, 2023-08-06:
@Nadezhda-n looks like inches bad https://github.com/andreika-git/gerbmerge/blob/43eb62470565f5f408cf8094047624bc43f90183/gerbmerge/jobs.py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 mm good?

@Nadezhda-n please change units to mm manually so that we could move forward

Nadezhda-n, 2023-08-08:
> @Nadezhda-n looks like inches bad https://github.com/andreika-git/gerbmerge/blob/43eb62470565f5f408cf8094047624bc43f90183/gerbmerge/jobs.py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 mm good?
>
> @Nadezhda-n please change units to mm manually so that we could move forward

Я не понимаю, где я должна изменить дюймы в мм, я ведь не делаю выгрузку вручную? А работаю я в мм

rusefillc, 2023-08-08:
я вот что осознал: в других местах выгрузка работает
похоже нужно один раз сделать выгрузку drill руками, и это просто поменяет настройки в проекте
и автоматические выгрузки тоже начнут работать, если я угадал проблему

Qwerty-OFF, 2023-08-08:
Кажется дело было в старых герберах в той же папке, использовались они вместо свежих

rusefillc, 2023-08-08:
https://github.com/andreika-git/hellen-one/issues/321 created to clean gerbers folder prior to export

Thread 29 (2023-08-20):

document USB pins on schematics

rusefillc, 2023-08-20:
we rely on nucleo USB connectivity let's mention this on the schematics. See also https://github.com/rusefi/stim/issues/28

```
#define EFI_USB_SERIAL_PORT GPIOA
#define EFI_USB_SERIAL_PIN_DM 11
#define EFI_USB_SERIAL_PIN_DP 12
```

Nadezhda-n, 2023-10-30:
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

Qwerty-OFF, 2023-12-10:
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

Closed 2023-12-10.

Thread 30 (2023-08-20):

CAN should use PD0 & PD1

rusefillc, 2023-08-20:
печаль
```
#define EFI_USB_SERIAL_PORT GPIOA
#define EFI_USB_SERIAL_PIN_DM 11
#define EFI_USB_SERIAL_PIN_DP 12
```

```
#define CAN_PORT GPIOA
#define CAN_PIN_RX 11
#define CAN_PIN_TX 12
```

rusefillc, 2023-08-20:
попробую перерезать CAN_TX CAN_RX и кину сопли на

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

rusefillc, 2023-08-21:
на схеме CN11 снизу обрезаны два GND пина, для уточнения вот эти пины используем для CAN шины теперь

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

rusefillc, 2023-08-21:
там возможно эти пины два раза выведены - ты смотришь на CN9

я как-то так получилось использовал другие на CN11, давай уже для простоты используем их

https://os.mbed.com/platforms/ST-Nucleo-F429ZI/

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

Nadezhda-n, 2023-08-21:
> попробую перерезать CAN_TX CAN_RX и кину сопли на
>
> 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

Резать еще что-то надо?
Или дублирует выводы просто?

rusefillc, 2023-08-21:
на плате 0.2 я отрезал старые CAN трассы

на rev C трассы будут вести только на PD0/PD1 и не будет CAN трасс на PA10/PA11

Nadezhda-n, 2023-08-21:
> на CN11, давай уже для прост

оки
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

Qwerty-OFF, 2023-12-10:
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

Closed 2023-12-10.

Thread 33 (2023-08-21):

LEDs for +5v inputs

rusefillc, 2023-08-21:
we should have two red LEDs for the two +5v inputs

https://rusefi.com/docs/pinouts/stim/?connector=main&pin=1B
https://rusefi.com/docs/pinouts/stim/?connector=main&pin=2B

Nadezhda-n, 2023-08-21:
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
не уверенна насчет номиналов, по аналогии на маленький ток сделала

Nadezhda-n, 2023-08-21:
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

Closed 2023-08-21.

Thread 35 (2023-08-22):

second CAN bus

rusefillc, 2023-08-22:
на нуклео наверняка есть вторая КАН шина? можно нам её тоже на неиспользуемые пины superseal?

Qwerty-OFF, 2023-12-10:
PB6/PB12. OUT0 перемещен с PB12 на PD8.
Установить чип CAN и вывести CAN на via?

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

rusefillc, 2023-12-10:
> Установить чип CAN

да

> вывести CAN на via?

пока да, у нас там есть via на разъёме - но мы пока не будет на разъём

Qwerty-OFF, 2023-12-10:
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

rusefillc, 2024-01-04:
>  OUT0 перемещен с PB12 на PD8.

жутко извиняюсь, но хочется уточнить: это единственное изменение распиновки и несовместимость между ревизиями A и С?

Qwerty-OFF, 2024-01-04:
Кажется больше ничего не трогали. Есть вероятность путаницы номеров CAN1/CAN2, если ты пытаешься запустить оба сразу

Closed 2024-10-18.

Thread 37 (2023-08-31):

push button to reset +12v power

rusefillc, 2023-08-31:
asking for normal-connect, push-disconnect push button to reset +12v power line

Qwerty-OFF, 2023-12-10:
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

rusefillc, 2023-12-10:
@Qwerty-OFF как сложно, а нельзя вот просто кнопкой? или ток слишком большой?

Qwerty-OFF, 2023-12-10:
Нормально замкнутая кнопка это экзотика. Могу поставить переключатель on/off

rusefillc, 2023-12-10:
@Qwerty-OFF согласен на on/off

Closed 2023-12-10.

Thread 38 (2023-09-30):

+12 digital inputs

rusefillc, 2023-09-30:
How do test brake switch? see https://github.com/rusefi/hellen154hyundai/issues/120

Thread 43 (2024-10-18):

rev C changelog

rusefillc, 2024-10-18:
Вот теперь точно нужно завести rev C стимуляторы

Мы кажется двигали CAN шину и кажется это влияло на что-то?

хочется улучшить https://github.com/rusefi/stim?tab=readme-ov-file#rev-c

rusefillc, 2024-10-18:
rev C заработала! https://github.com/rusefi/stim/issues/47

Closed 2024-10-18.

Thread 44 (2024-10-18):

nucleo CAN header is missing in BOM

rusefillc, 2024-10-18:
what's the level of effort to have any component which would have these two positions in the BOM?

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

Closed 2024-10-19.

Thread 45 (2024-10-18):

rev C вся нуклео не включается от 12 вольт

rusefillc, 2024-10-18:
на rev C есть кнопка

при питании от 12 вольт в одном положении ничего не светится

при питании от 12 вольт в другом положении мигает LD4 наверху нуклео, но на основном блоке нуклео ничего не светится

прошивка stim начинает мигать голубым только при подключении microUSB

Qwerty-OFF, 2024-10-18:
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
Джампер сюда. Питание 12В максимум

Qwerty-OFF, 2024-10-19:
Мы будем использовать E5V
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

Qwerty-OFF, 2024-10-19:
Поставил стабилизатор на 5В

rusefillc, 2024-11-01:
extra nucleo pin for 5v

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

rusefillc, 2024-11-01:
JP3 подвинул, как на картинке

третий пин J20 припаял, как на картинке

LD4 мигает
LD6 не горит, прошивка не стартует @Qwerty-OFF

Qwerty-OFF, 2024-11-02:
JP3 передвинь в E5V, та картинка была для внешних 12В

Closed 2024-11-02.

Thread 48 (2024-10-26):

just damaged rev C number 2 while playing with 10R 20W between 19C and 20C

rusefillc, 2024-10-26:
we were trying to add real load to improve detection of bad ECUs

specific board was passing good with 0.58v MAP as expected using 8B ``Reference voltage out 2 (MAP) 0.6v``

suddenly voltage check started to fail

```
 * BAD channel 4 (MAP): voltage 0.363921568 (raw 32) not in range (0.670109504..0.000000000)
 ***********************************************
 ***********************************************
 * BAD channel 4 (MAP): voltage 0.363921568 (raw 32) not in range (0.670109504..0.000000000)
 ***********************************************
 ***********************************************
 * BAD channel 4 (MAP): voltage 0.363921568 (raw 32) not in range (0.670109504..0.000000000)
```

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

jharvey, 2024-10-26:
@rusefillc @Qwerty-OFF
While TC4427 can drive around 1.5A, the MUX CD4067BM96 is only rated for around +/- 20mA. With a recommended max of +/- 10ma continuous. It appears the MUX is not protected against overcurrent, so it's likely the 10R damaged that channel of the MUX, perhaps other channels as well.

rusefillc, 2024-11-02:
my bad that was a software issue

Closed 2024-11-02.

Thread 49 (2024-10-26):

Suggestions to add to stim board.

jharvey, 2024-10-26:
Suggestion to add a MUXed voltage reference which can be used to validate that each op-amp's measurement circuit is operating properly. Something similar to the below could be a added to one of the MUXed inputs allowing the Nucleo to validate that the opamp circuit has not been damaged or validate the opamp circuit is preforming badly for some reason.
https://jlcpcb.com/partdetail/Onsemi-TL431BVLPRAG/C513084

Also suggest to add LED"s to the TC4427, this would allow to validate that the TC4427 is attempting to drive either high or low.

rusefillc, 2024-10-26:
@jharvey there is that amazing https://xyproblem.info/ convention:

``The XY problem is asking about your attempted solution rather than your actual problem.``

within that convention I see  ``Others try to help user with Y, but are confused because Y seems like a strange problem to want to solve.``

so, WHY?

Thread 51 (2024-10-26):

WO2 stim

jharvey, 2024-10-26:
I think a WO2 stim could be made with a simple stack of resistors between Vref and GND, generating a variety of voltages. To understand the voltages we want for a basic test stimulator, we could take some measures then find resistors to make that happen. Lost of great WO2 data at the below link.
https://waltech.com/cszcms/wide-band-oxygen-sensor-project-report

jharvey, 2024-10-27:
With WO2 connected, could I get these voltages as indicated in the picture. Any multimeter would suffice.
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

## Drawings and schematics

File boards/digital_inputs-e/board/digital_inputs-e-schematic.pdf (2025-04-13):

# 11 VSS 12 D

# 11 VSS 12 D

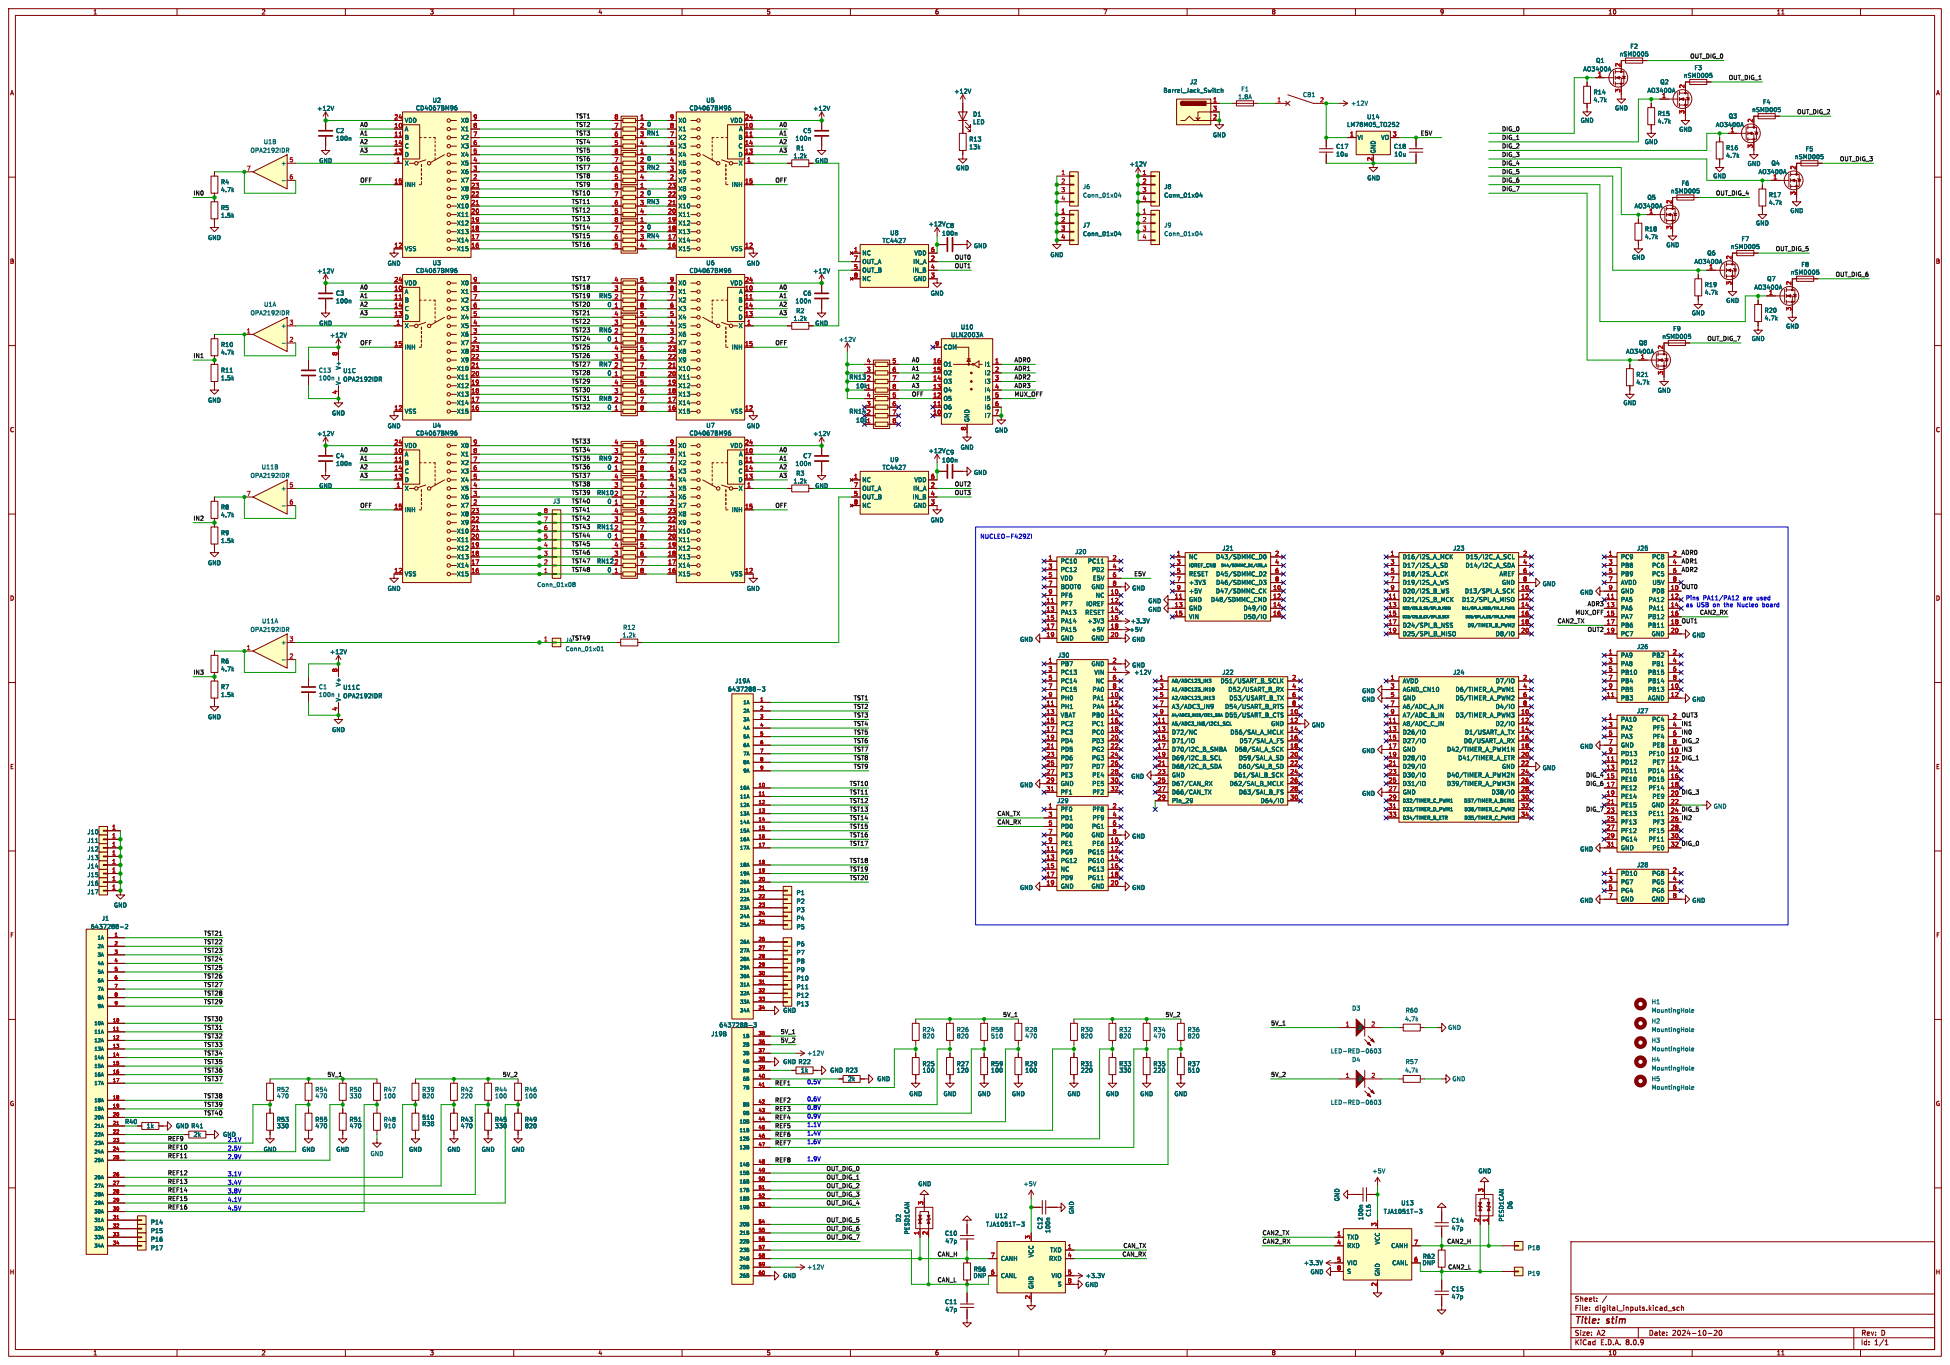
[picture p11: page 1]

as USB on the Nucleo board
CAN2_RX

47p R62 DNP C¹⁶ 100n GND GND

3 RXD 4 VIO 5 CANL 6 CANH 7 S

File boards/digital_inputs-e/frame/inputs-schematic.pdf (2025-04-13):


as USB on the Nucleo board
CAN2_RX

3 RXD 4 VIO 5 CANL 6 CANH 7 S

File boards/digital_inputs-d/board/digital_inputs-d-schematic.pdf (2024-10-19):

# 11 VSS 12 D

- 2 +

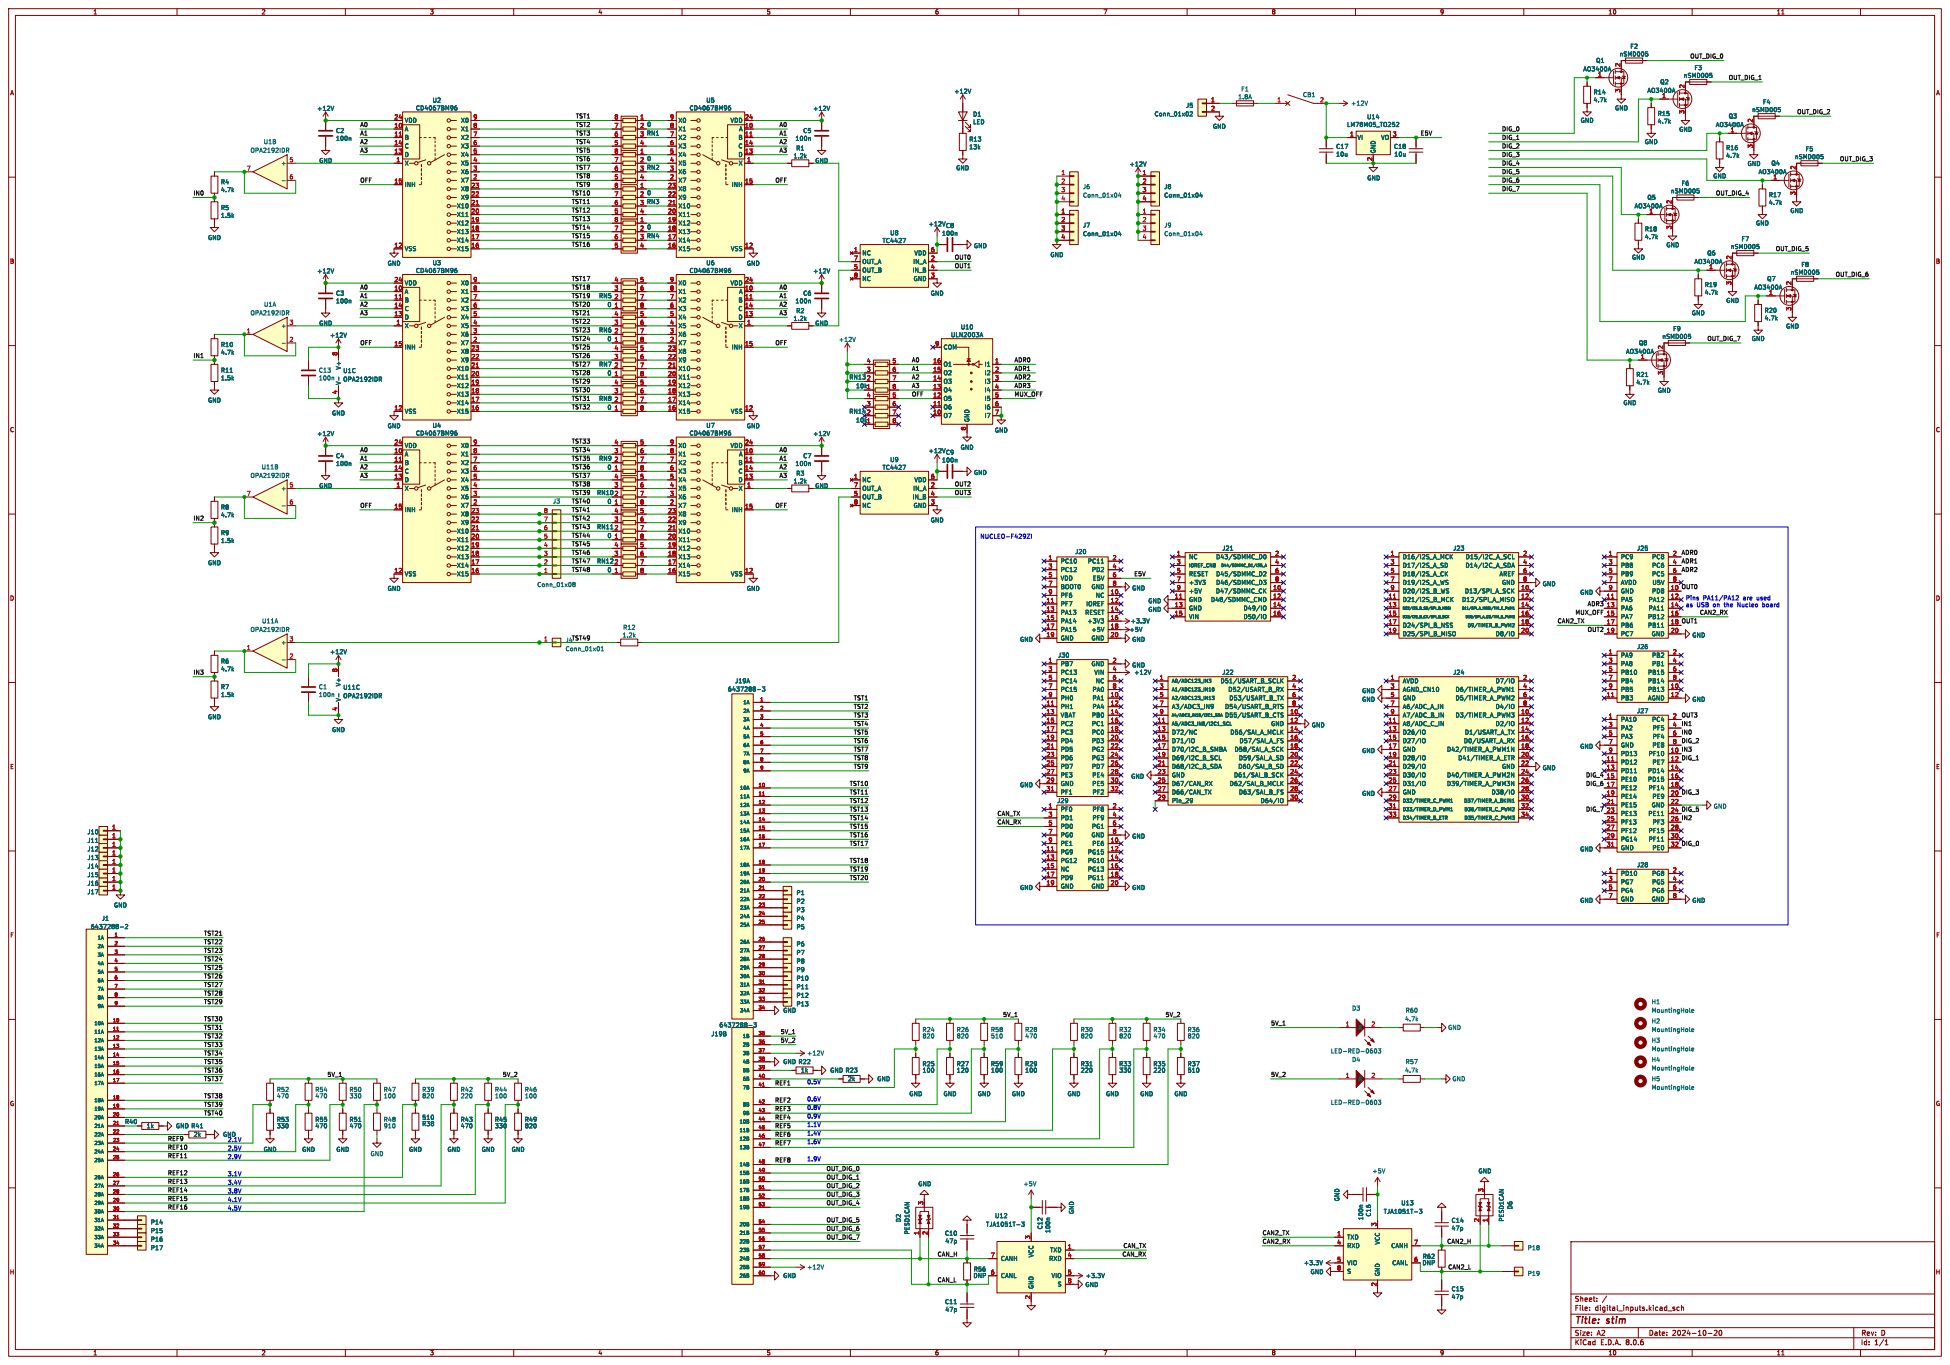
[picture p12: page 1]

8 COM 9 GND GND GND GND

as USB on the Nucleo board

3 RXD 4 VIO 5 CANL 6 CANH 7 S

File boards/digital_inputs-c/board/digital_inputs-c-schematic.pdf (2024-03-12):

# 11 VSS 12 D

# 11 VSS 12 D

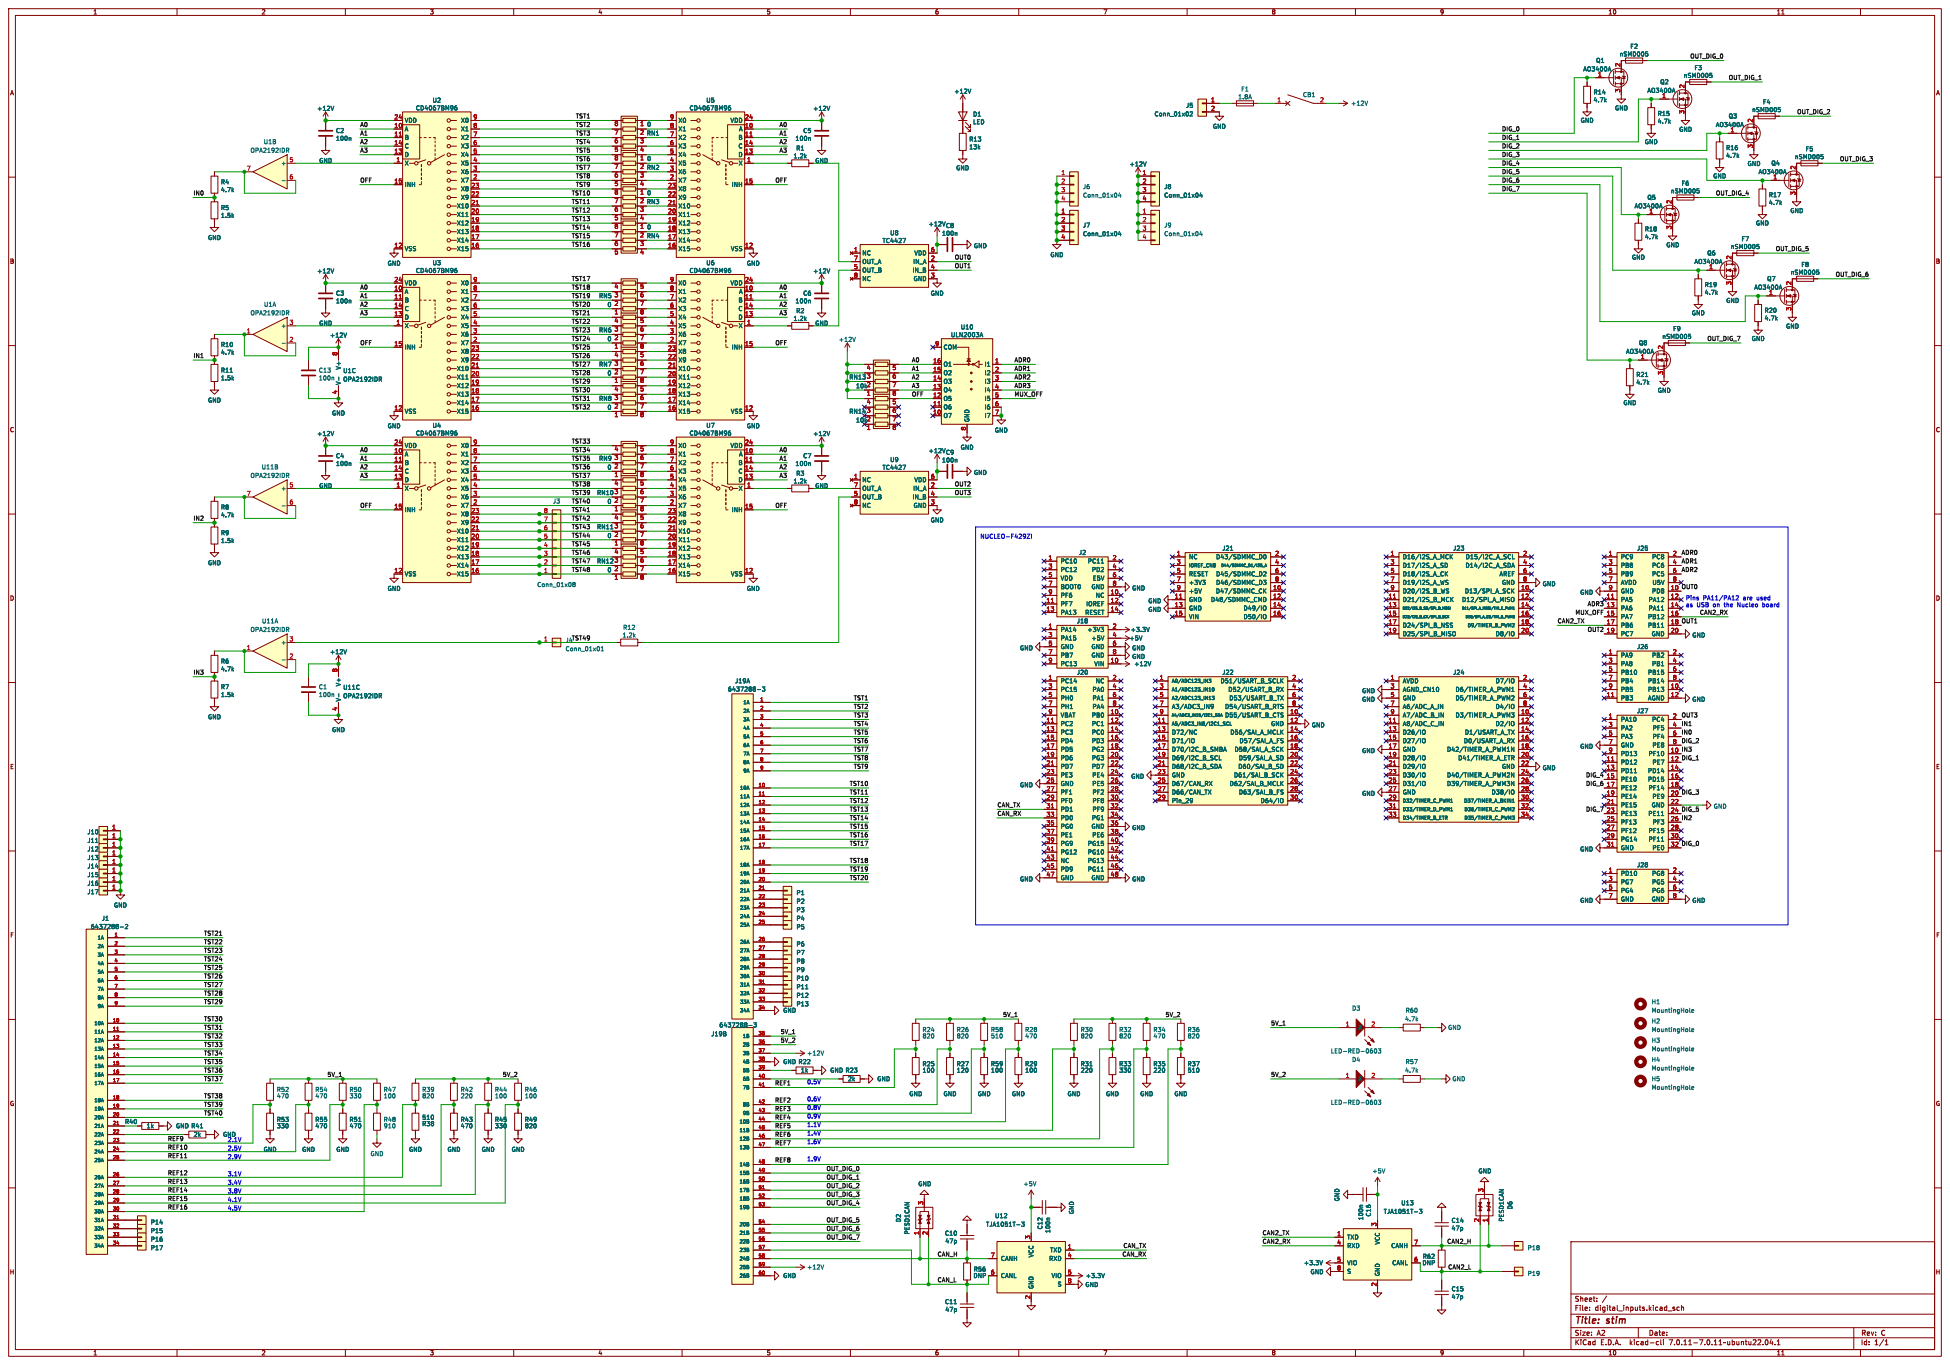
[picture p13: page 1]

as USB on the Nucleo board NUCLEO-F429ZI

3 RXD 4 VIO 5 CANL 6 CANH 7 S

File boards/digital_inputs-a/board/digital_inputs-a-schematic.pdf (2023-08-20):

# +12V 1 - 2 + 3 U1A OPA2192IDR 1

4.7k R5

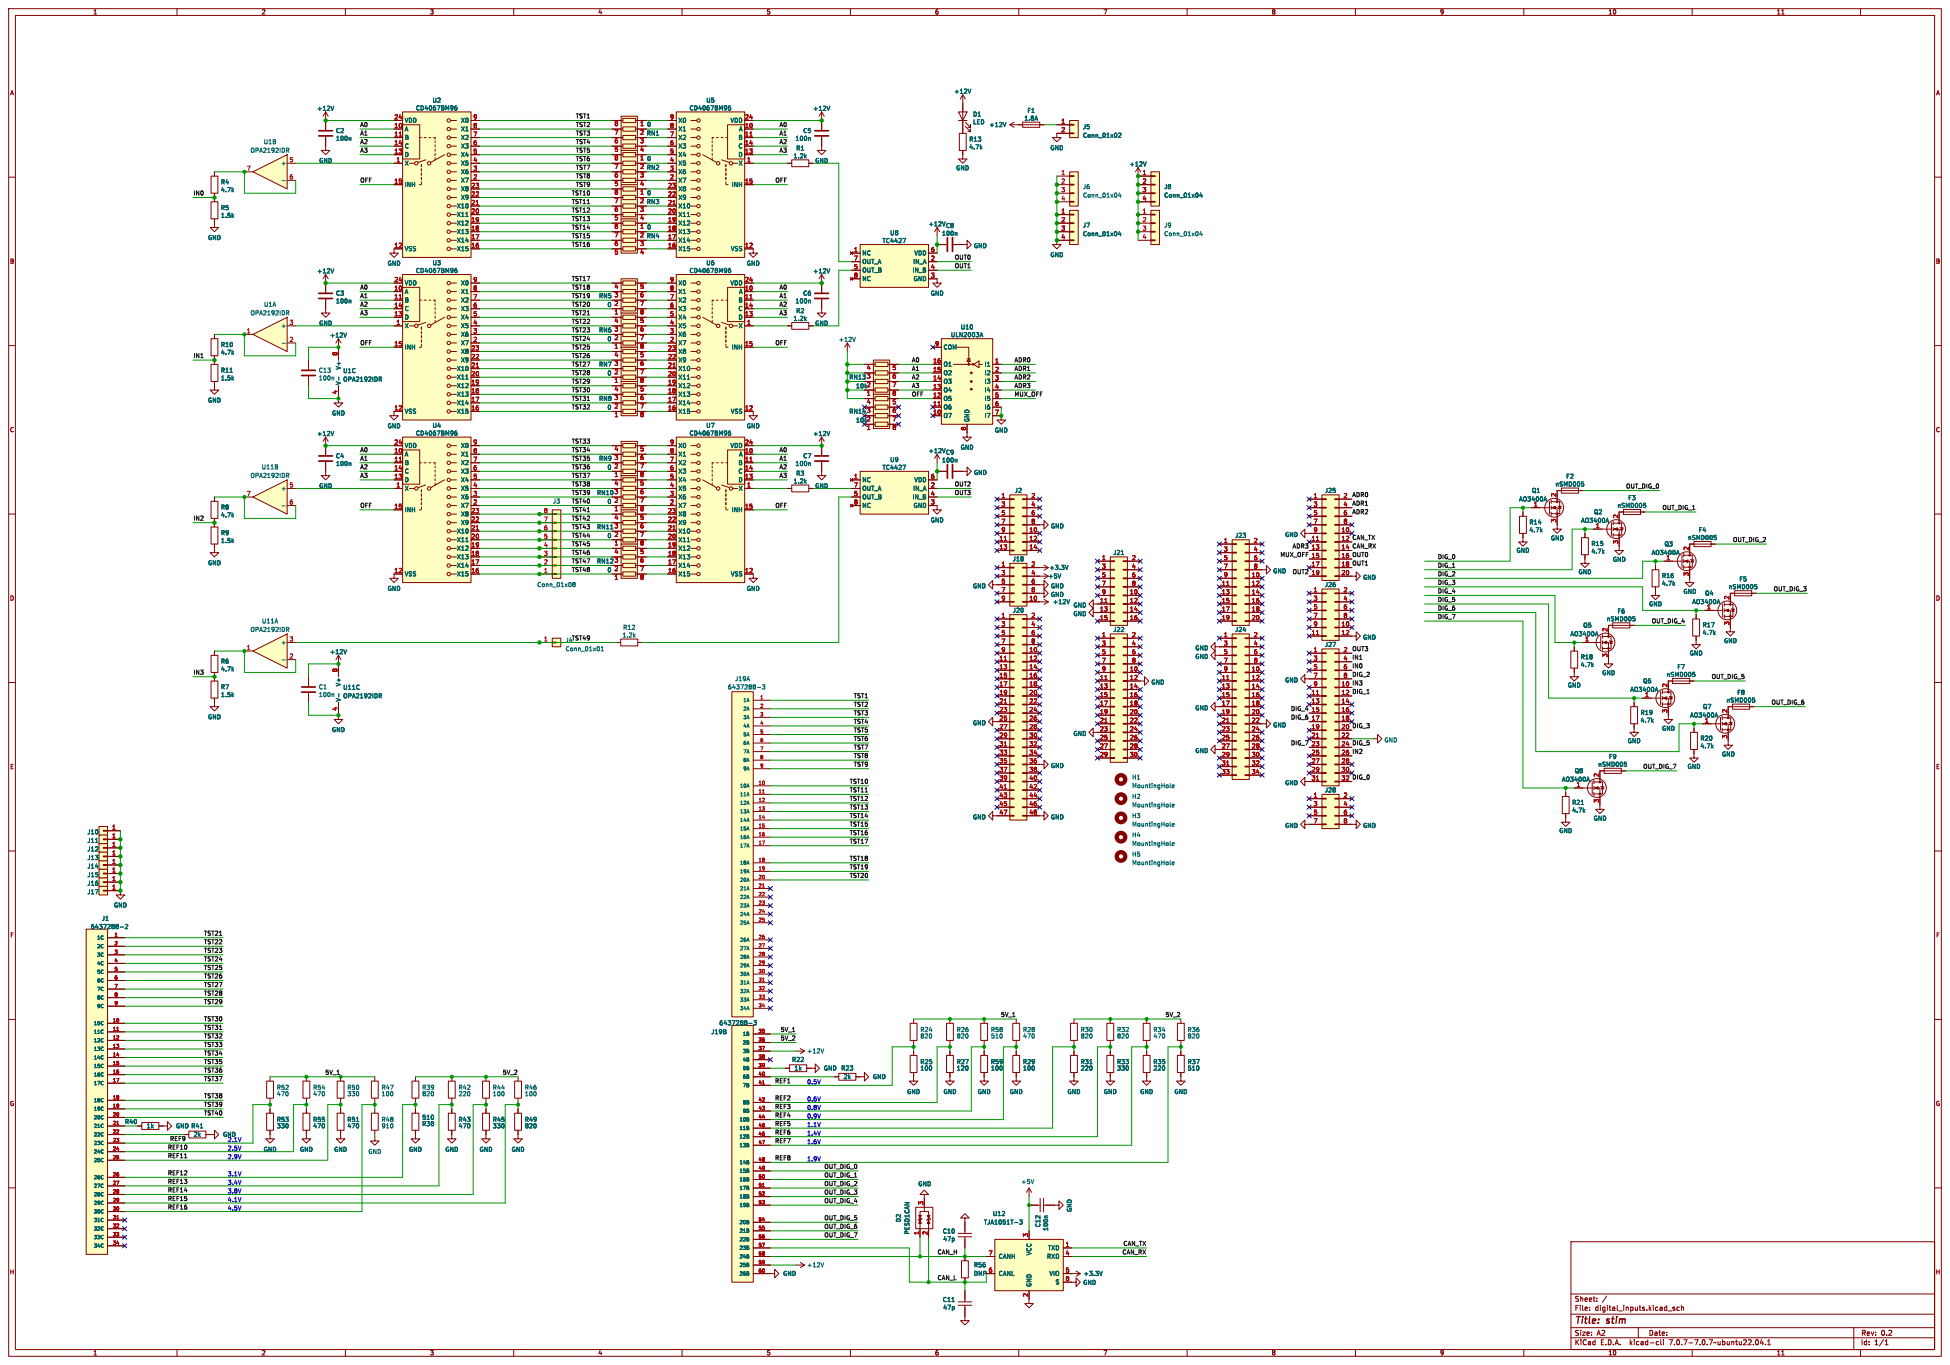
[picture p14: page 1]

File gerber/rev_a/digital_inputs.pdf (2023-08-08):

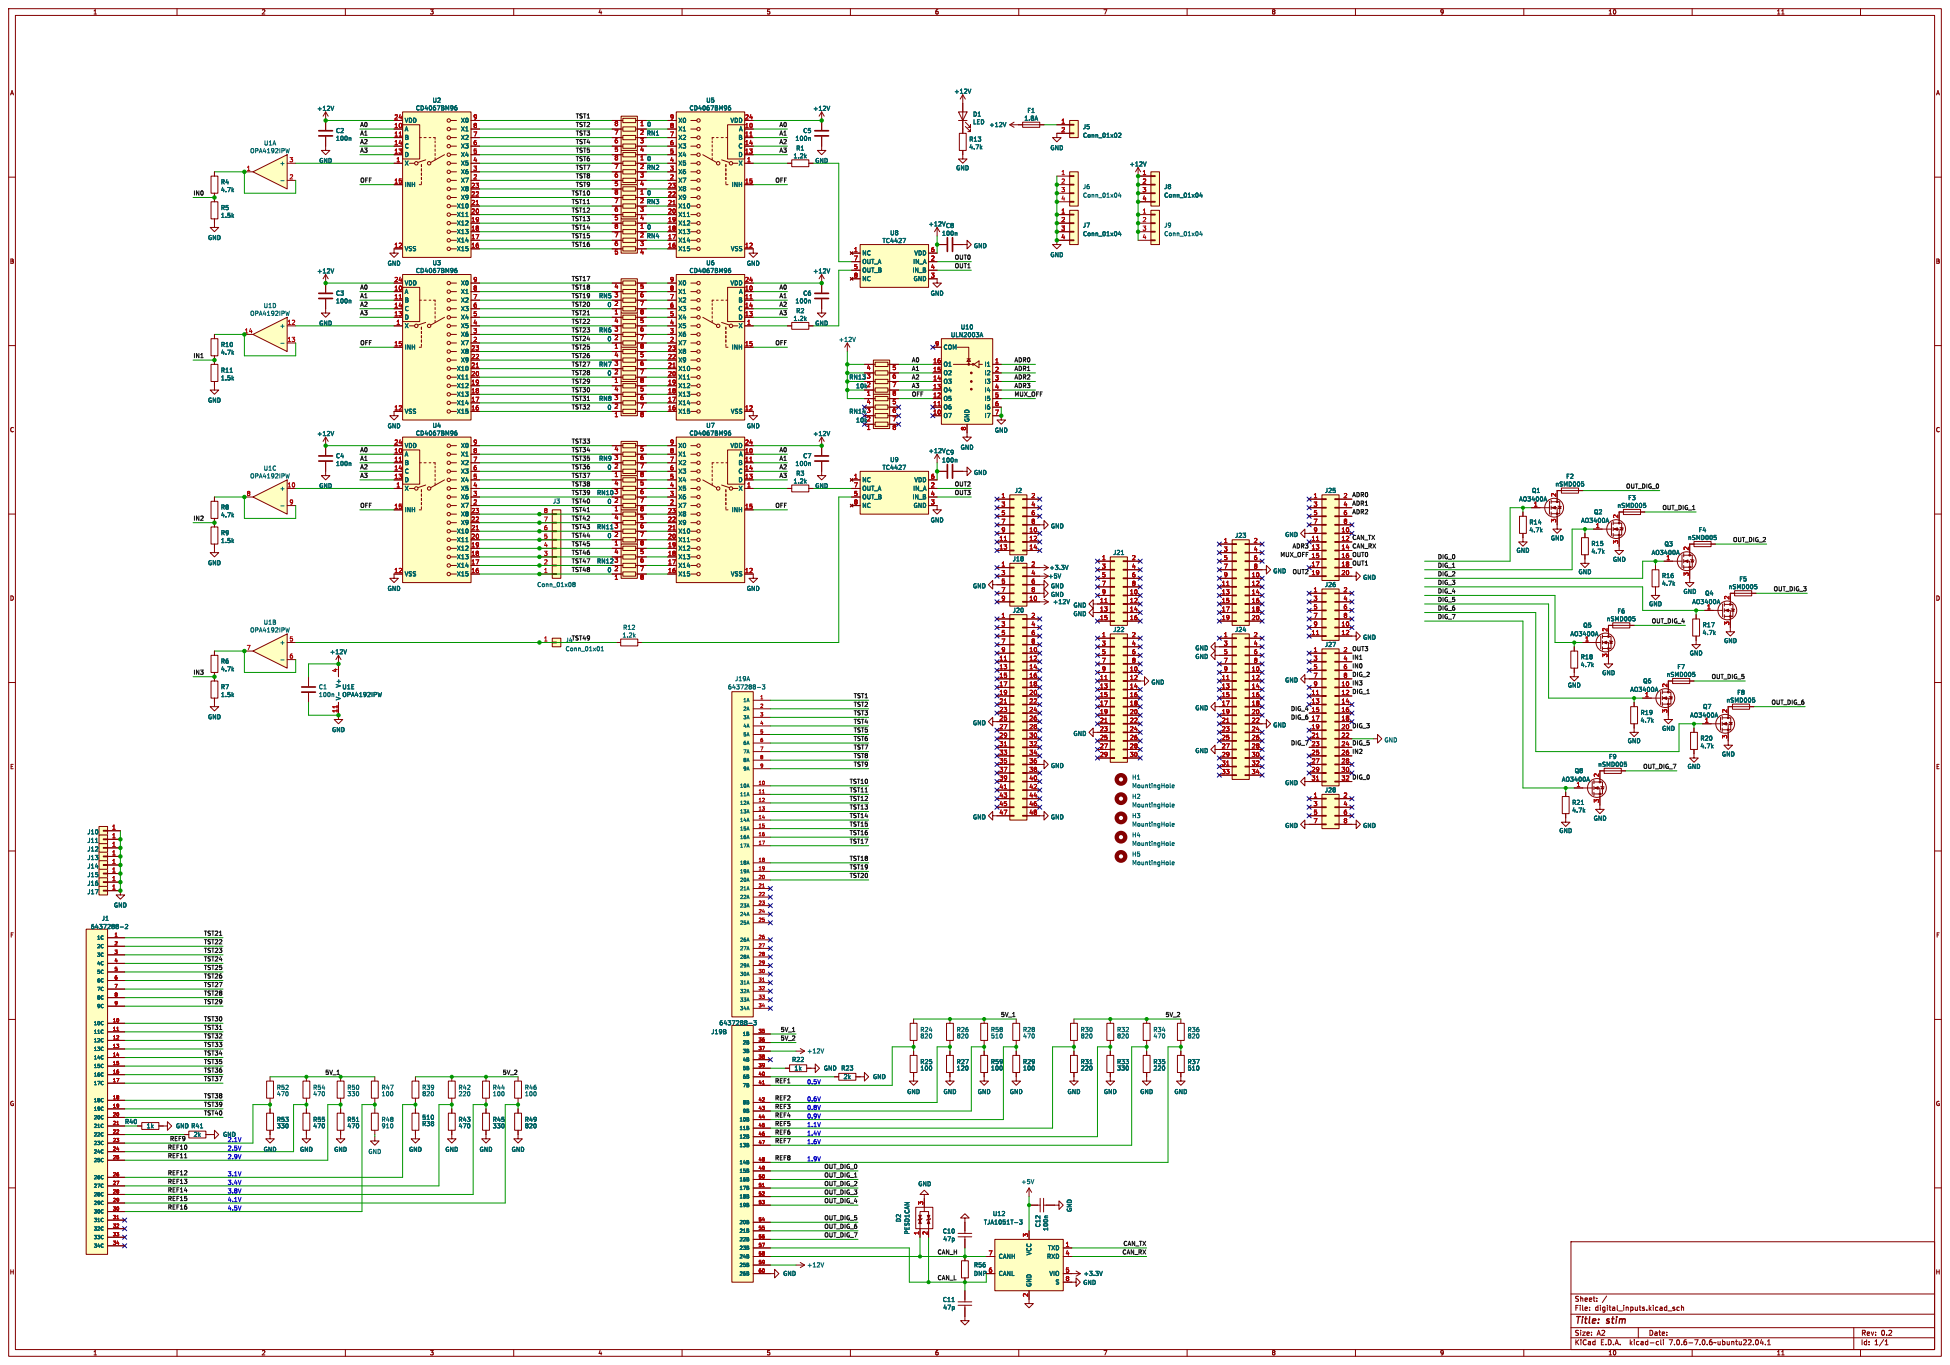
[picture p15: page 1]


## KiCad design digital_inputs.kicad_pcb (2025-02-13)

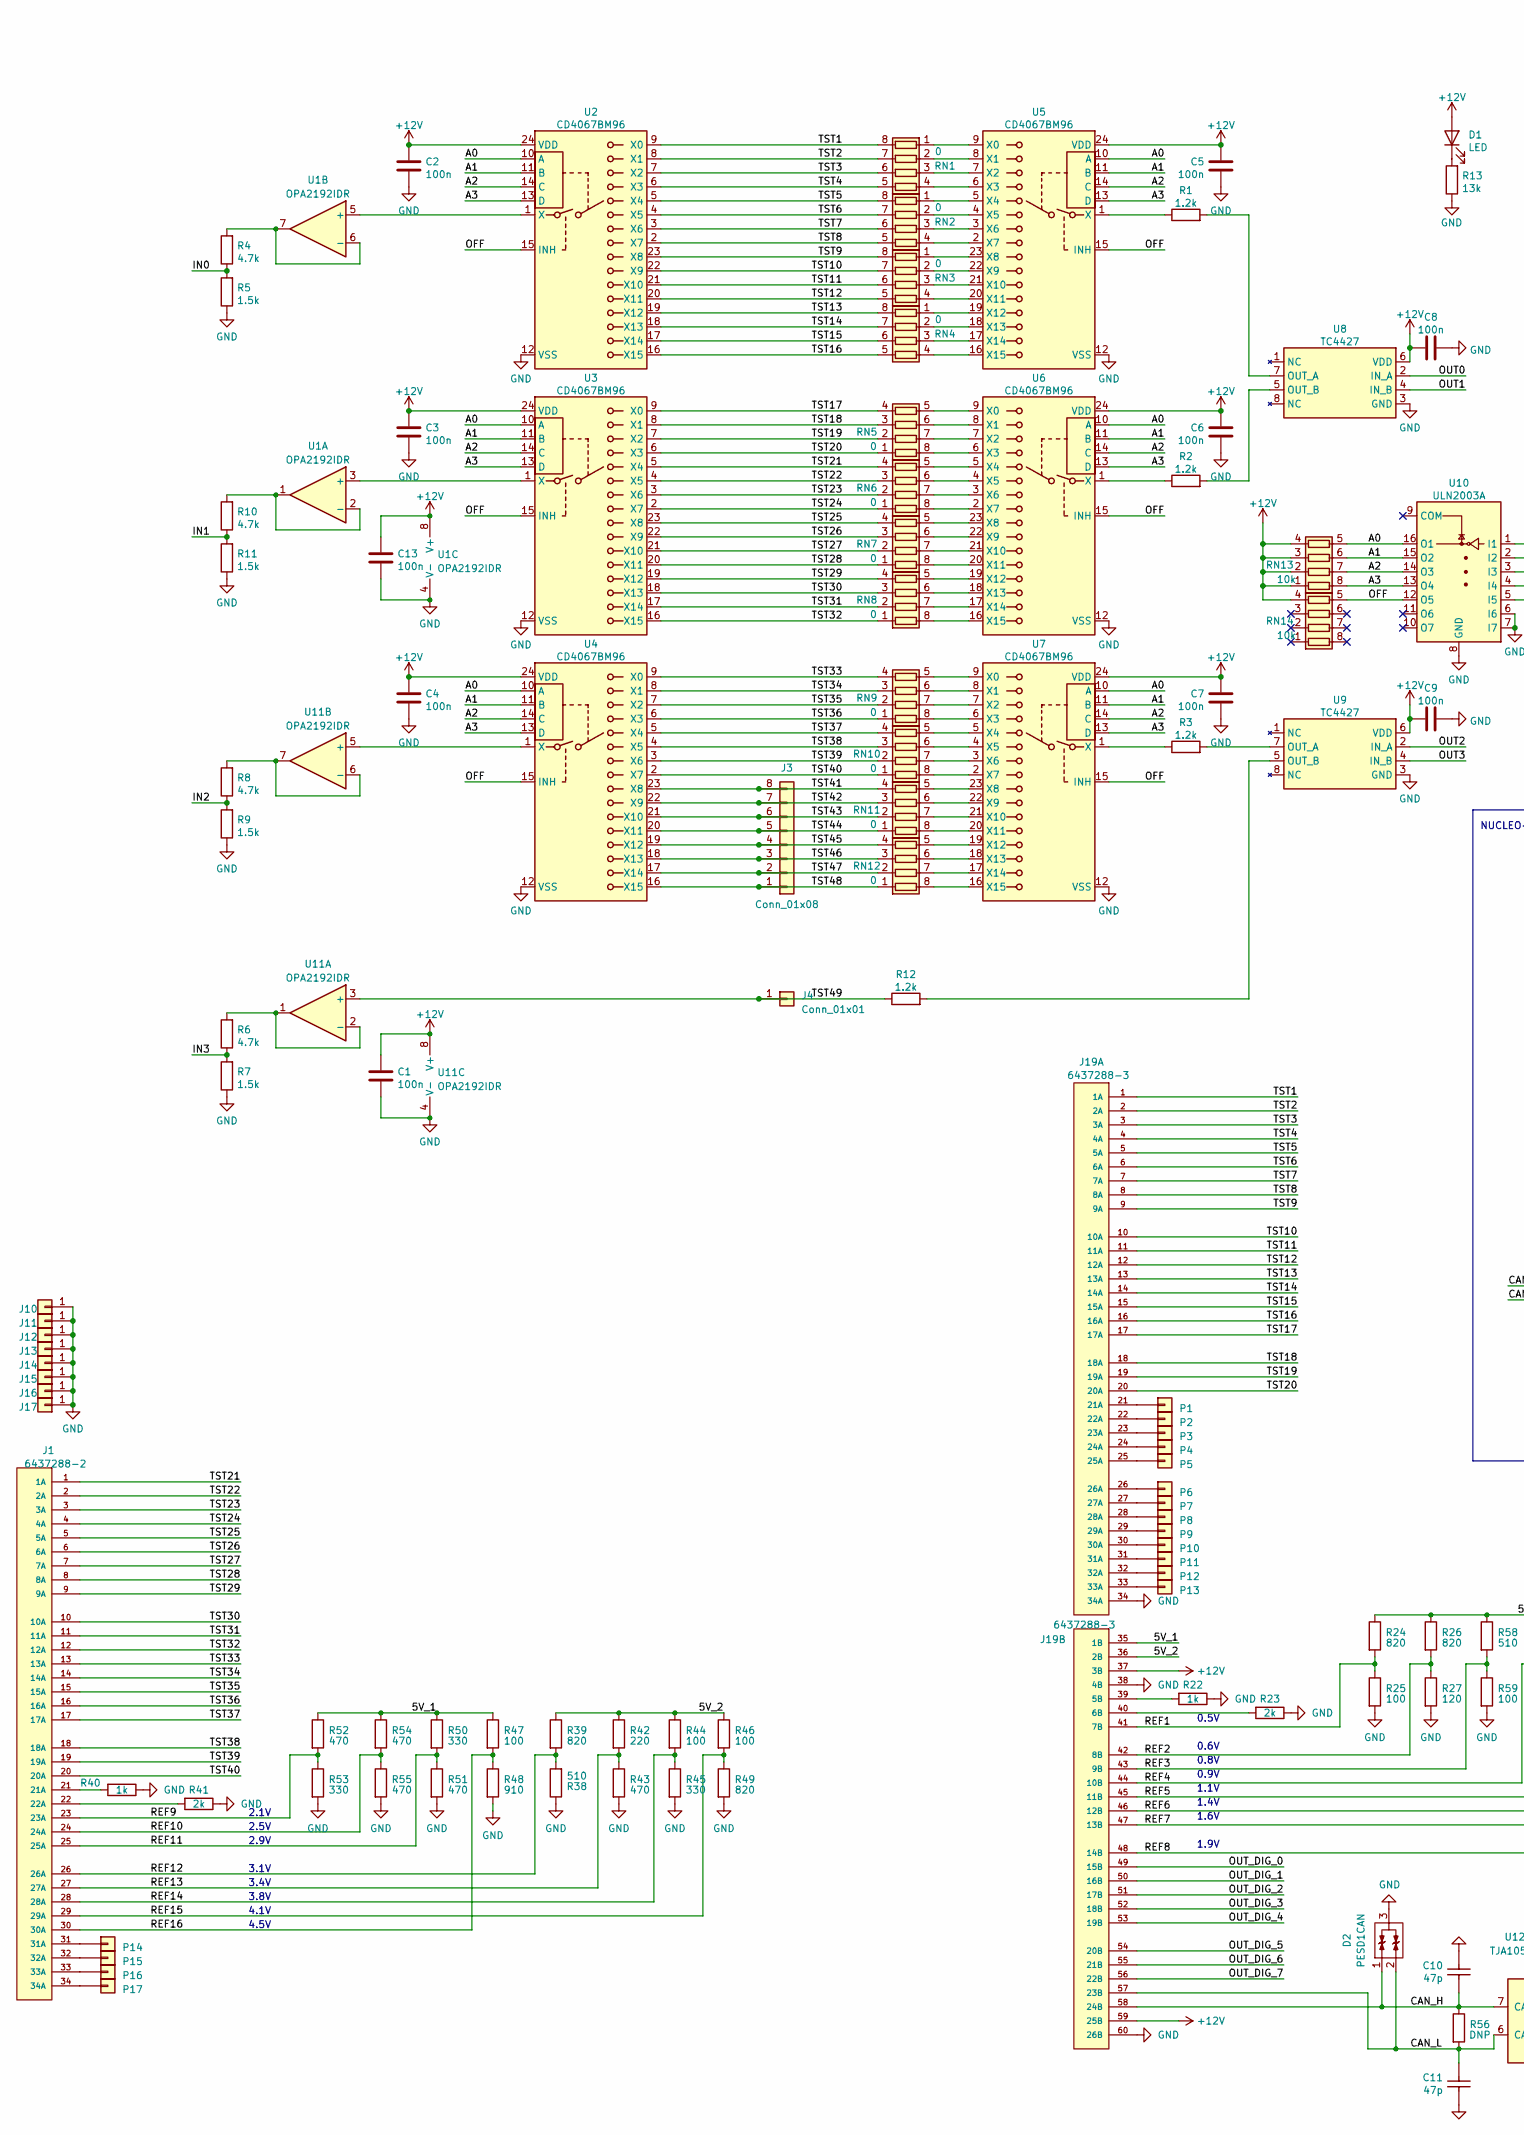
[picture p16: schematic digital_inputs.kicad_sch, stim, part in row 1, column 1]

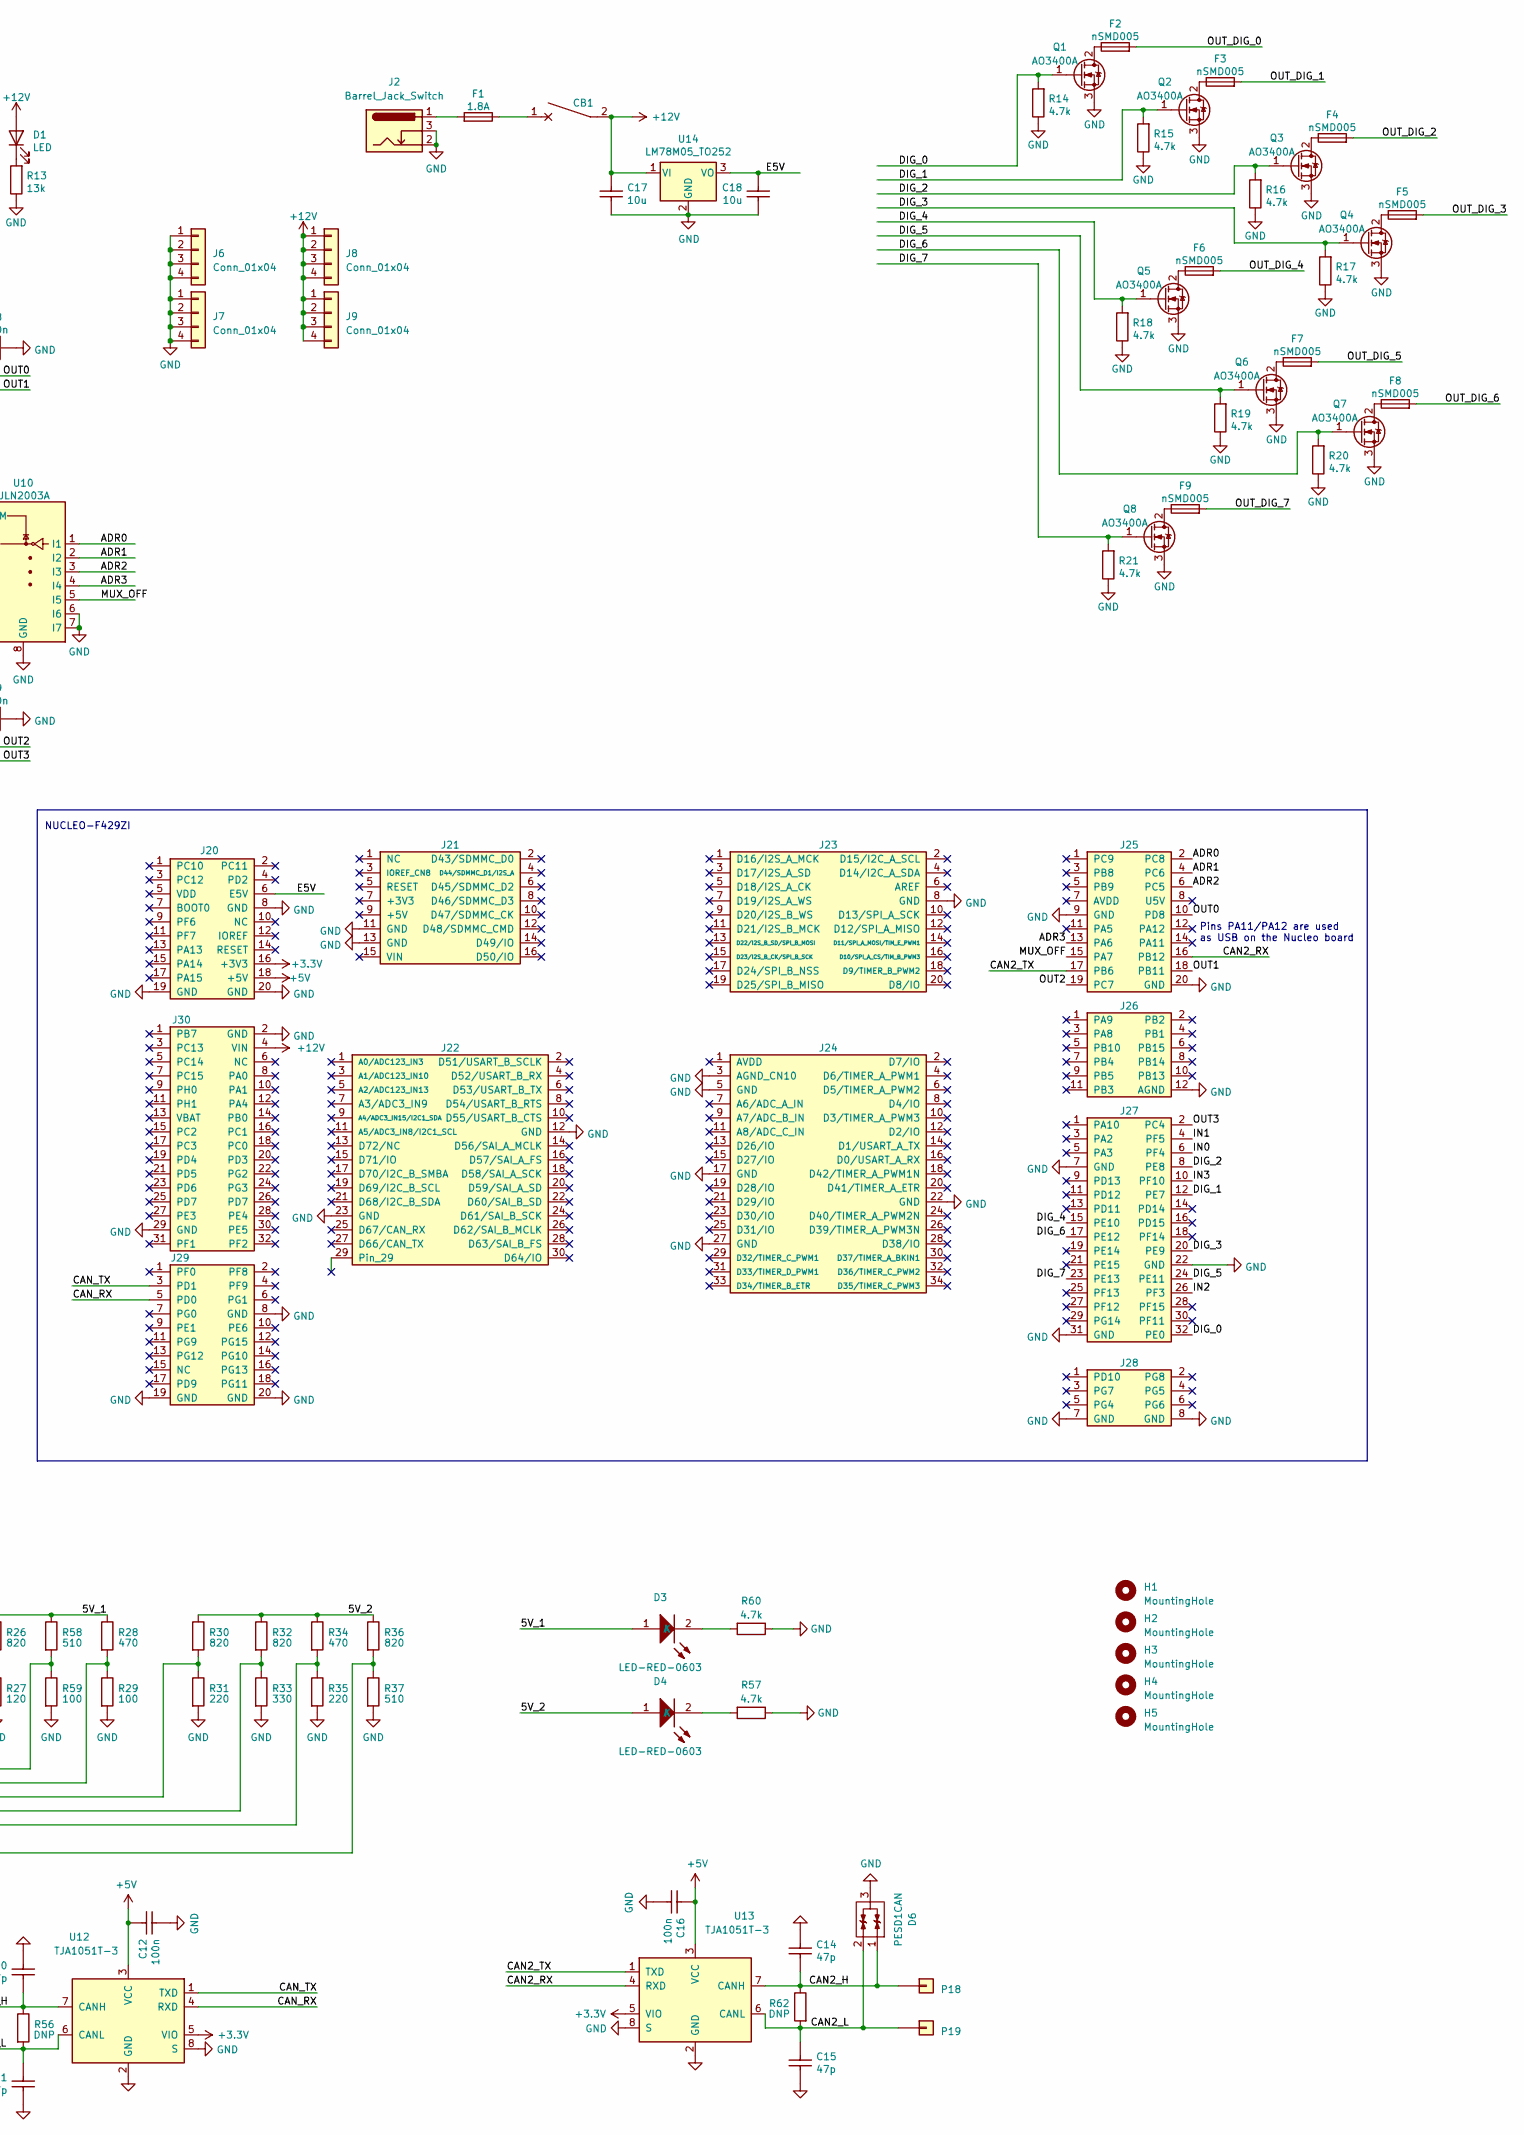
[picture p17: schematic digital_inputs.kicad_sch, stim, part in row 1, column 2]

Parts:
C1, C2, C3, C4, C5, C6, C7, C8, C9, C12, C13, C16: 100n; C_0603_1608Metric; LCSC C14663
C10, C11, C14, C15: 47p; C_0603_1608Metric; LCSC C1671
C17, C18: 10u; C_0805_2012Metric; LCSC C15850
CB1: CircuitBreaker_1P; RS601HL-1010011BB; LCSC C2885782
D1: LED; LED_0805_2012Metric; LCSC C2297
D2, D6: PESD1CAN; SOT-23; LCSC C343993
D3, D4: LED-RED-0603; LED-0603; LCSC C2286
F1: 1.8A; Fuse_1206_3216Metric; LCSC C369161
F2, F3, F4, F5, F6, F7, F8, F9: nSMD005; Fuse_1206_3216Metric; LCSC C369153
H1, H2, H3, H4, H5: MountingHole; MountingHole_3.2mm_M3
J1: 6437288-2
J2: Barrel_Jack_Switch; BarrelJack_GCT_DCJ200-10-A_Horizontal; LCSC C111567
J3: Conn_01x08; TerminalBlock_Phoenix_MKDS-1,5-8-5.08_1x08_P5.08mm_Horizont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
J4: Conn_01x01; SolderWire-0.75sqmm_1x01_D1.25mm_OD2.3mm
J6, J7, J8, J9: Conn_01x04; TerminalBlock_Phoenix_MKDS-1,5-4-5.08_1x04_P5.08mm_Horizont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
J10, J11, J12, J13, J14, J15, J16, J17: Conn_01x01; MountingHole_3.2mm_M3_Pad_Via
J19: 6437288-3; TE_6437288-3; LCSC C591769
J20, J25, J29: Conn_02x10_Odd_Even; PinHeader_2x10_P2.54mm_Vertical; LCSC C92266
J21: Conn_02x08_Odd_Even; PinHeader_2x08_P2.54mm_Vertical
J22: Conn_02x15_Odd_Even; PinHeader_2x15_P2.54mm_Vertical
J23: Conn_02x10_Odd_Even; PinHeader_2x10_P2.54mm_Vertical
J24: Conn_02x17_Odd_Even; PinHeader_2x17_P2.54mm_Vertical
J26: Conn_02x06_Odd_Even; PinHeader_2x06_P2.54mm_Vertical
J27: Conn_02x16_Odd_Even; PinHeader_2x16_P2.54mm_Vertical; LCSC C132130
J28: Conn_02x04_Odd_Even; PinHeader_2x04_P2.54mm_Vertical
J30: Conn_02x14_Odd_Even; PinHeader_2x16_P2.54mm_Vertical
P1, P2, P3, P4, P5, P6, P7, P8, P9, P10, P11, P12, P13, P14, P15, P16, P17, P18, P19: Pad; PAD-TH
Q1, Q2, Q3, Q4, Q5, Q6, Q7, Q8: AO3400A; SOT-23; LCSC C20917
R1, R2, R3, R12: 1.2k; R_1206_3216Metric; LCSC C26035
R4, R6, R8, R10, R14, R15, R16, R17, R18, R19, R20, R21, R57, R60: 4.7k; R_0603_1608Metric; LCSC C23162
R5, R7, R9, R11: 1.5k; R_0603_1608Metric; LCSC C22843
R13: 13k; R_0603_1608Metric; LCSC C22797
R22, R40: 1k; R_0603_1608Metric; LCSC C21190
R23, R41: 2k; R_0603_1608Metric; LCSC C4190
R24, R26, R30, R32, R36, R39, R49: 820; R_0603_1608Metric; LCSC C23253
R25, R29, R44, R46, R47, R59: 100; R_0603_1608Metric; LCSC C22775
R27: 120; R_0603_1608Metric; LCSC C22787
R28, R34, R43, R51, R52, R54, R55: 470; R_0603_1608Metric; LCSC C23179
R31, R35, R42: 220; R_0603_1608Metric; LCSC C22962
R33, R45, R50, R53: 330; R_0603_1608Metric; LCSC C23138
R37, R38, R58: 510; R_0603_1608Metric; LCSC C23193
R48: 910; R_0603_1608Metric; LCSC C23264
R56, R62: DNP; R_0603_1608Metric
RN1, RN2, RN3, RN4, RN5, RN6, RN7, RN8, RN9, RN10, RN11, RN12: 0; R_Array_Convex_4x0603; LCSC C327053
RN13, RN14: 10k; R_Array_Convex_4x0603; LCSC C29718
U1, U11: OPA2192IDR; SO-8_3.9x4.9mm_P1.27mm; LCSC C110074
U2, U3, U4, U5, U6, U7: CD4067BM96; SOIC-24W_7.5x15.4mm_P1.27mm; LCSC C6525
U8, U9: TC4427; SOIC-8_3.9x4.9mm_P1.27mm; LCSC C20551
U10: ULN2003A; SOIC-16_3.9x9.9mm_P1.27mm; LCSC C7512
U12, U13: TJA1051T-3; SOIC-8_3.9x4.9mm_P1.27mm; LCSC C38695
U14: LM78M05_TO252; TO-252-2; LCSC C58069

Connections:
+3.3V: J20.16 (+3V3), U12.5 (VIO), U13.5 (VIO)
+5V: C12.2, C16.2, J20.18 (+5V), U12.3 (VCC), U13.3 (VCC)
+12V: C1.2, C2.2, C3.2, C4.2, C5.2, C6.2, C7.2, C8.1, C9.1, C13.2, C17.2, CB1.2, D1.2 (A), J8.1, J8.2, J8.3, J8.4, J9.1, J9.2, J9.3, J9.4, J19.37 (3B), J19.59 (25B), J30.4 (VIN), RN13.1 (R1.1), RN13.2 (R2.1), RN13.3 (R3.1), RN13.4 (R4.1), RN14.4 (R4.1), U1.8 (V+), U2.24 (VDD), U3.24 (VDD), U4.24 (VDD), U5.24 (VDD), U6.24 (VDD), U7.24 (VDD), U8.6 (VDD), U9.6 (VDD), U11.8 (V+), U14.1 (VI)
/5V_1: D3.1 (A), J19.35 (1B), R24.1, R26.1, R28.1, R47.1, R50.1, R52.1, R54.1, R58.1
/5V_2: D4.1 (A), J19.36 (2B), R30.1, R32.1, R34.1, R36.1, R39.1, R42.1, R44.1, R46.1
/A0: RN13.5 (R4.2), U2.10 (A), U3.10 (A), U4.10 (A), U5.10 (A), U6.10 (A), U7.10 (A), U10.16 (O1)
/A1: RN13.6 (R3.2), U2.11 (B), U3.11 (B), U4.11 (B), U5.11 (B), U6.11 (B), U7.11 (B), U10.15 (O2)
/A2: RN13.7 (R2.2), U2.14 (C), U3.14 (C), U4.14 (C), U5.14 (C), U6.14 (C), U7.14 (C), U10.14 (O3)
/A3: RN13.8 (R1.2), U2.13 (D), U3.13 (D), U4.13 (D), U5.13 (D), U6.13 (D), U7.13 (D), U10.13 (O4)
/ADR0: J25.2 (PC8), U10.1 (I1)
/ADR1: J25.4 (PC6), U10.2 (I2)
/ADR2: J25.6 (PC5), U10.3 (I3)
/ADR3: J25.13 (PA6), U10.4 (I4)
/CAN2_H: C14.1, D6.1 (G), P18.1, R62.1, U13.7 (CANH)
/CAN2_L: C15.2, D6.2 (D), P19.1, R62.2, U13.6 (CANL)
/CAN2_RX: J25.16 (PB12), U13.4 (RXD)
/CAN2_TX: J25.17 (PB6), U13.1 (TXD)
/CAN_H: C10.1, D2.1 (G), J19.58 (24B), R56.1, U12.7 (CANH)
/CAN_L: C11.2, D2.2 (D), J19.57 (23B), R56.2, U12.6 (CANL)
/CAN_RX: J29.5 (PD0), U12.4 (RXD)
/CAN_TX: J29.3 (PD1), U12.1 (TXD)
/DIG_0: J27.32 (PE0), Q1.1 (G), R14.2
/DIG_1: J27.12 (PE7), Q2.1 (G), R15.2
/DIG_2: J27.8 (PE8), Q3.1 (G), R16.2
/DIG_3: J27.20 (PE9), Q4.1 (G), R17.2
/DIG_4: J27.15 (PE10), Q5.1 (G), R18.2
/DIG_5: J27.24 (PE11), Q6.1 (G), R19.2
/DIG_6: J27.17 (PE12), Q7.1 (G), R20.2
/DIG_7: J27.23 (PE13), Q8.1 (G), R21.2
/E5V: C18.2, J20.6 (E5V), U14.3 (VO)
/IN0: J27.6 (PF4), R4.1, R5.2
/IN1: J27.4 (PF5), R10.1, R11.2
/IN2: J27.26 (PF3), R8.1, R9.2
/IN3: J27.10 (PF10), R6.1, R7.2
/MUX_OFF: J25.15 (PA7), U10.5 (I5)
/OFF: RN14.5 (R4.2), U2.15 (INH), U3.15 (INH), U4.15 (INH), U5.15 (INH), U6.15 (INH), U7.15 (INH), U10.12 (O5)
/OUT0: J25.10 (PD8), U8.2 (IN_A)
/OUT1: J25.18 (PB11), U8.4 (IN_B)
/OUT2: J25.19 (PC7), U9.2 (IN_A)
/OUT3: J27.2 (PC4), U9.4 (IN_B)
/OUT_DIG_0: F2.2, J19.49 (15B)
/OUT_DIG_1: F3.2, J19.50 (16B)
/OUT_DIG_2: F4.2, J19.51 (17B)
/OUT_DIG_3: F5.2, J19.52 (18B)
/OUT_DIG_4: F6.2, J19.53 (19B)
/OUT_DIG_5: F7.2, J19.54 (20B)
/OUT_DIG_6: F8.2, J19.55 (21B)
/OUT_DIG_7: F9.2, J19.56 (22B)
/REF1: J19.41 (7B), R24.2, R25.1
/REF2: J19.42 (8B), R26.2, R27.1
/REF3: J19.43 (9B), R58.2, R59.1
/REF4: J19.44 (10B), R28.2, R29.1
/REF5: J19.45 (11B), R30.2, R31.1
/REF6: J19.46 (12B), R32.2, R33.1
/REF7: J19.47 (13B), R34.2, R35.1
/REF8: J19.48 (14B), R36.2, R37.1
/REF9: J1.23 (23A), R52.2, R53.1
/REF10: J1.24 (24A), R54.2, R55.1
/REF11: J1.25 (25A), R50.2, R51.1
/REF12: J1.26 (26A), R38.2, R39.2
/REF13: J1.27 (27A), R42.2, R43.1
/REF14: J1.28 (28A), R44.2, R45.1
/REF15: J1.29 (29A), R46.2, R49.1
/REF16: J1.30 (30A), R47.2, R48.1
/TST1: J19.1 (1A), RN1.8 (R1.2), U2.9 (X0)
/TST2: J19.2 (2A), RN1.7 (R2.2), U2.8 (X1)
/TST3: J19.3 (3A), RN1.6 (R3.2), U2.7 (X2)
/TST4: J19.4 (4A), RN1.5 (R4.2), U2.6 (X3)
/TST5: J19.5 (5A), RN2.8 (R1.2), U2.5 (X4)
/TST6: J19.6 (6A), RN2.7 (R2.2), U2.4 (X5)
/TST7: J19.7 (7A), RN2.6 (R3.2), U2.3 (X6)
/TST8: J19.8 (8A), RN2.5 (R4.2), U2.2 (X7)
/TST9: J19.9 (9A), RN3.8 (R1.2), U2.23 (X8)
/TST10: J19.10 (10A), RN3.7 (R2.2), U2.22 (X9)
/TST11: J19.11 (11A), RN3.6 (R3.2), U2.21 (X10)
/TST12: J19.12 (12A), RN3.5 (R4.2), U2.20 (X11)
/TST13: J19.13 (13A), RN4.8 (R1.2), U2.19 (X12)
/TST14: J19.14 (14A), RN4.7 (R2.2), U2.18 (X13)
/TST15: J19.15 (15A), RN4.6 (R3.2), U2.17 (X14)
/TST16: J19.16 (16A), RN4.5 (R4.2), U2.16 (X15)
/TST17: J19.17 (17A), RN5.4 (R4.1), U3.9 (X0)
/TST18: J19.18 (18A), RN5.3 (R3.1), U3.8 (X1)
/TST19: J19.19 (19A), RN5.2 (R2.1), U3.7 (X2)
/TST20: J19.20 (20A), RN5.1 (R1.1), U3.6 (X3)
/TST21: J1.1 (1A), RN6.4 (R4.1), U3.5 (X4)
/TST22: J1.2 (2A), RN6.3 (R3.1), U3.4 (X5)
/TST23: J1.3 (3A), RN6.2 (R2.1), U3.3 (X6)
/TST24: J1.4 (4A), RN6.1 (R1.1), U3.2 (X7)
/TST25: J1.5 (5A), RN7.4 (R4.1), U3.23 (X8)
/TST26: J1.6 (6A), RN7.3 (R3.1), U3.22 (X9)
/TST27: J1.7 (7A), RN7.2 (R2.1), U3.21 (X10)
/TST28: J1.8 (8A), RN7.1 (R1.1), U3.20 (X11)
/TST29: J1.9 (9A), RN8.4 (R4.1), U3.19 (X12)
/TST30: J1.10 (10A), RN8.3 (R3.1), U3.18 (X13)
/TST31: J1.11 (11A), RN8.2 (R2.1), U3.17 (X14)
/TST32: J1.12 (12A), RN8.1 (R1.1), U3.16 (X15)
/TST33: J1.13 (13A), RN9.4 (R4.1), U4.9 (X0)
/TST34: J1.14 (14A), RN9.3 (R3.1), U4.8 (X1)
/TST35: J1.15 (15A), RN9.2 (R2.1), U4.7 (X2)
/TST36: J1.16 (16A), RN9.1 (R1.1), U4.6 (X3)
/TST37: J1.17 (17A), RN10.4 (R4.1), U4.5 (X4)
/TST38: J1.18 (18A), RN10.3 (R3.1), U4.4 (X5)
/TST39: J1.19 (19A), RN10.2 (R2.1), U4.3 (X6)
/TST40: J1.20 (20A), RN10.1 (R1.1), U4.2 (X7)
/TST41: J3.8, RN11.4 (R4.1), U4.23 (X8)
/TST42: J3.7, RN11.3 (R3.1), U4.22 (X9)
/TST43: J3.6, RN11.2 (R2.1), U4.21 (X10)
/TST44: J3.5, RN11.1 (R1.1), U4.20 (X11)
/TST45: J3.4, RN12.4 (R4.1), U4.19 (X12)
/TST46: J3.3, RN12.3 (R3.1), U4.18 (X13)
/TST47: J3.2, RN12.2 (R2.1), U4.17 (X14)
/TST48: J3.1, RN12.1 (R1.1), U4.16 (X15)
/TST49: J4.1, R12.1, U11.3 (+)
GND: C1.1, C2.1, C3.1, C4.1, C5.1, C6.1, C7.1, C8.2, C9.2, C10.2, C11.1, C12.1, C13.1, C14.2, C15.1, C16.1, C17.1, C18.1, D2.3 (S), D6.3 (S), J2.2, J2.3, J6.1, J6.2, J6.3, J6.4, J7.1, J7.2, J7.3, J7.4, J10.1, J11.1, J12.1, J13.1, J14.1, J15.1, J16.1, J17.1, J19.34 (34A), J19.38 (4B), J19.60 (26B), J20.8 (GND), J20.19 (GND), J20.20 (GND), J21.11 (GND), J21.13 (GND), J22.12 (GND), J22.23 (GND), J23.8 (GND), J24.3 (AGND_CN10), J24.5 (GND), J24.17 (GND), J24.22 (GND), J24.27 (GND), J25.9 (GND), J25.20 (GND), J26.12 (AGND), J27.7 (GND), J27.22 (GND), J27.31 (GND), J28.7 (GND), J28.8 (GND), J29.8 (GND), J29.19 (GND), J29.20 (GND), J30.2 (GND), J30.29 (GND), Q1.3 (S), Q2.3 (S), Q3.3 (S), Q4.3 (S), Q5.3 (S), Q6.3 (S), Q7.3 (S), Q8.3 (S), R5.1, R7.1, R9.1, R11.1, R13.1, R14.1, R15.1, R16.1, R17.1, R18.1, R19.1, R20.1, R21.1, R22.1, R23.1, R25.2, R27.2, R29.2, R31.2, R33.2, R35.2, R37.2, R38.1, R40.1, R41.1, R43.2, R45.2, R48.2, R49.2, R51.2, R53.2, R55.2, R57.1, R59.2, R60.1, U1.4 (V-), U2.12 (VSS), U3.12 (VSS), U4.12 (VSS), U5.12 (VSS), U6.12 (VSS), U7.12 (VSS), U8.3 (GND), U9.3 (GND), U10.6 (I6), U10.7 (I7), U10.8 (GND), U11.4 (V-), U12.2 (GND), U12.8 (S), U13.2 (GND), U13.8 (S), U14.2 (GND)
unnamed: CB1.1, F1.1
unnamed: D1.1 (K), R13.2
unnamed: D3.2 (K), R60.2
unnamed: D4.2 (K), R57.2
unnamed: F1.2, J2.1
unnamed: J1.21 (21A), R40.2
unnamed: J1.22 (22A), R41.2
unnamed: J1.31 (31A), P14.1
unnamed: J1.32 (32A), P15.1
unnamed: J1.33 (33A), P16.1
unnamed: J1.34 (34A), P17.1
unnamed: J19.21 (21A), P1.1
unnamed: J19.22 (22A), P2.1
unnamed: J19.23 (23A), P3.1
unnamed: J19.24 (24A), P4.1
unnamed: J19.25 (25A), P5.1
unnamed: J19.26 (26A), P6.1
unnamed: J19.27 (27A), P7.1
unnamed: J19.28 (28A), P8.1
unnamed: J19.29 (29A), P9.1
unnamed: J19.30 (30A), P10.1
unnamed: J19.31 (31A), P11.1
unnamed: J19.32 (32A), P12.1
unnamed: J19.33 (33A), P13.1
unnamed: J19.39 (5B), R22.2
unnamed: J19.40 (6B), R23.2
unnamed: F2.1, Q1.2 (D)
unnamed: F3.1, Q2.2 (D)
unnamed: F4.1, Q3.2 (D)
unnamed: F5.1, Q4.2 (D)
unnamed: F6.1, Q5.2 (D)
unnamed: F7.1, Q6.2 (D)
unnamed: F8.1, Q7.2 (D)
unnamed: F9.1, Q8.2 (D)
unnamed: RN1.1 (R1.1), U5.9 (X0)
unnamed: RN1.2 (R2.1), U5.8 (X1)
unnamed: RN1.3 (R3.1), U5.7 (X2)
unnamed: RN1.4 (R4.1), U5.6 (X3)
unnamed: RN2.1 (R1.1), U5.5 (X4)
unnamed: RN2.2 (R2.1), U5.4 (X5)
unnamed: RN2.3 (R3.1), U5.3 (X6)
unnamed: RN2.4 (R4.1), U5.2 (X7)
unnamed: RN3.1 (R1.1), U5.23 (X8)
unnamed: RN3.2 (R2.1), U5.22 (X9)
unnamed: RN3.3 (R3.1), U5.21 (X10)
unnamed: RN3.4 (R4.1), U5.20 (X11)
unnamed: RN4.1 (R1.1), U5.19 (X12)
unnamed: RN4.2 (R2.1), U5.18 (X13)
unnamed: RN4.3 (R3.1), U5.17 (X14)
unnamed: RN4.4 (R4.1), U5.16 (X15)
unnamed: RN5.8 (R1.2), U6.6 (X3)
unnamed: RN5.7 (R2.2), U6.7 (X2)
unnamed: RN5.6 (R3.2), U6.8 (X1)
unnamed: RN5.5 (R4.2), U6.9 (X0)
unnamed: RN6.8 (R1.2), U6.2 (X7)
unnamed: RN6.7 (R2.2), U6.3 (X6)
unnamed: RN6.6 (R3.2), U6.4 (X5)
unnamed: RN6.5 (R4.2), U6.5 (X4)
unnamed: RN7.8 (R1.2), U6.20 (X11)
unnamed: RN7.7 (R2.2), U6.21 (X10)
unnamed: RN7.6 (R3.2), U6.22 (X9)
unnamed: RN7.5 (R4.2), U6.23 (X8)
unnamed: RN8.8 (R1.2), U6.16 (X15)
unnamed: RN8.7 (R2.2), U6.17 (X14)
unnamed: RN8.6 (R3.2), U6.18 (X13)
unnamed: RN8.5 (R4.2), U6.19 (X12)
unnamed: RN9.8 (R1.2), U7.6 (X3)
unnamed: RN9.7 (R2.2), U7.7 (X2)
unnamed: RN9.6 (R3.2), U7.8 (X1)
unnamed: RN9.5 (R4.2), U7.9 (X0)
unnamed: RN10.8 (R1.2), U7.2 (X7)
unnamed: RN10.7 (R2.2), U7.3 (X6)
unnamed: RN10.6 (R3.2), U7.4 (X5)
unnamed: RN10.5 (R4.2), U7.5 (X4)
unnamed: RN11.8 (R1.2), U7.20 (X11)
unnamed: RN11.7 (R2.2), U7.21 (X10)
unnamed: RN11.6 (R3.2), U7.22 (X9)
unnamed: RN11.5 (R4.2), U7.23 (X8)
unnamed: RN12.8 (R1.2), U7.16 (X15)
unnamed: RN12.7 (R2.2), U7.17 (X14)
unnamed: RN12.6 (R3.2), U7.18 (X13)
unnamed: RN12.5 (R4.2), U7.19 (X12)
unnamed: U1.3 (+), U3.1 (X)
unnamed: R10.2, U1.1, U1.2 (-)
unnamed: U1.5 (+), U2.1 (X)
unnamed: R4.2, U1.6 (-), U1.7
unnamed: R1.1, U5.1 (X)
unnamed: R2.1, U6.1 (X)
unnamed: R3.1, U7.1 (X)
unnamed: R1.2, U8.7 (OUT_A)
unnamed: R2.2, U8.5 (OUT_B)
unnamed: R3.2, U9.7 (OUT_A)
unnamed: R12.2, U9.5 (OUT_B)
unnamed: R6.2, U11.1, U11.2 (-)
unnamed: U4.1 (X), U11.5 (+)
unnamed: R8.2, U11.6 (-), U11.7

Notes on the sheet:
1.4V
3.8V
1.1V
Pins PA11/PA12 are used as USB on the Nucleo board
0.9V
1.6V
4.5V
3.4V
NUCLEO-F429ZI
0.5V
1.9V
0.8V
3.1V
2.1V
2.5V
0.6V
4.1V
2.9V

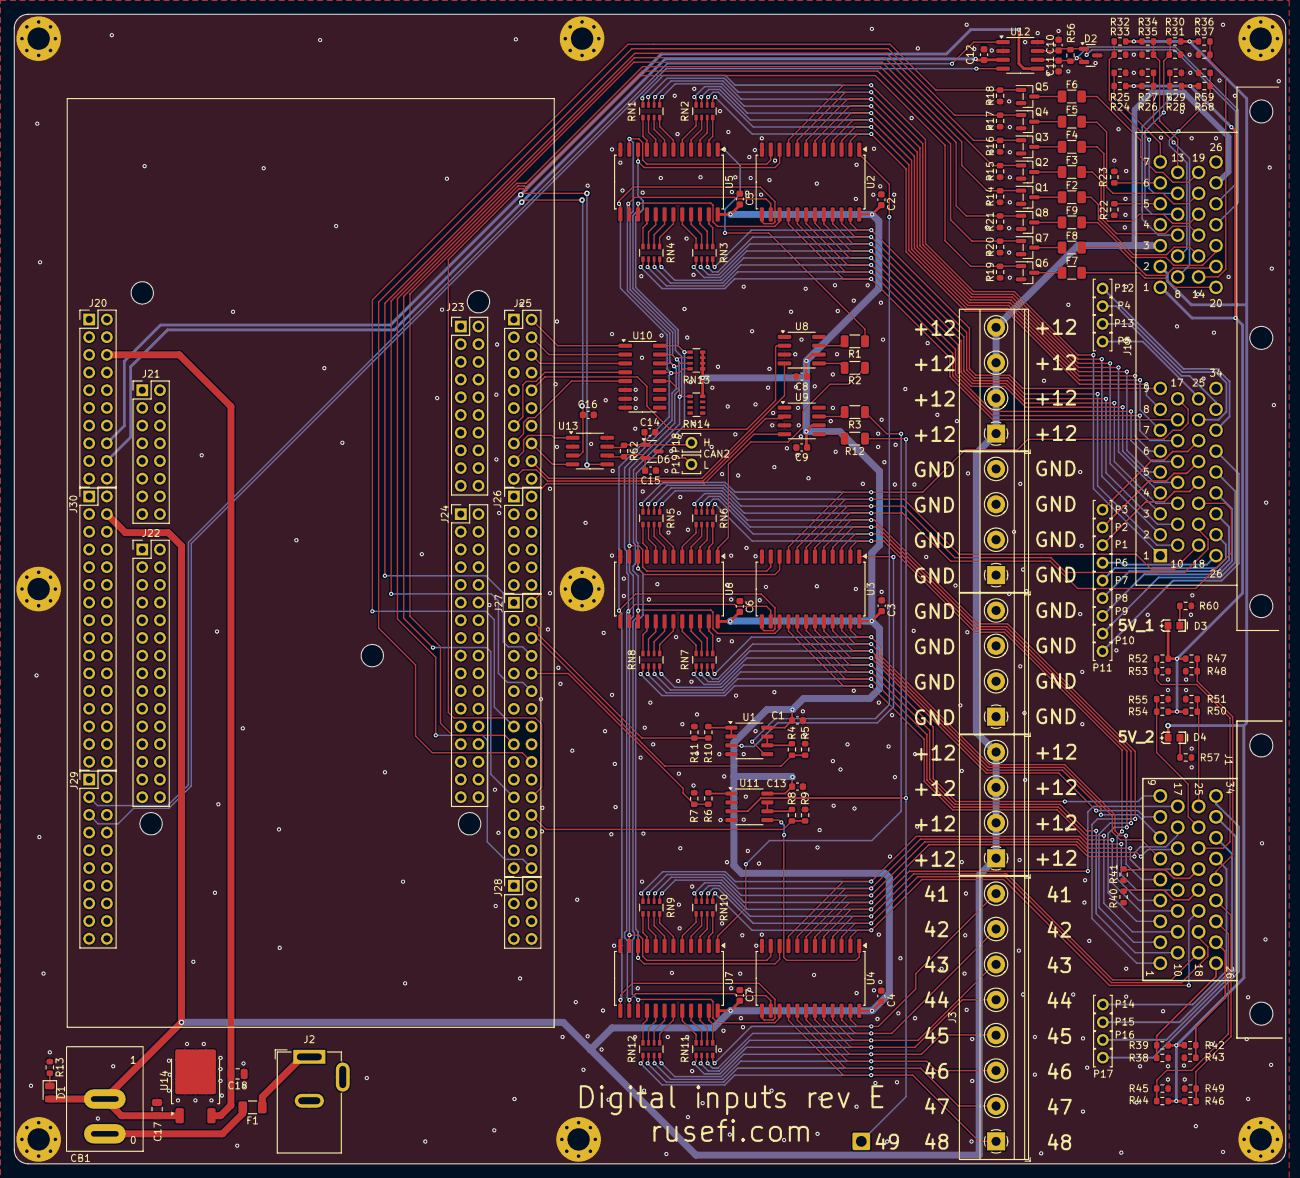
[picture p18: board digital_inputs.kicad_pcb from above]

Board: 2 copper layers, 182.5 x 165.0 mm, 182 parts (0 on the bottom side), 210 nets.

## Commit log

2021-07-19 Upd sch
    [stim.kicad_pcb, stim.kicad_sch]
2021-07-24 Upd sch & pcb
    [stim.kicad_pcb, stim.kicad_sch]
2021-07-25 Rename #8
    [digital_inputs-B_Cu.gbr, digital_inputs-B_Mask.gbr, digital_inputs-B_Paste.gbr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]
2021-07-28 Fab preview
    [digital_inputs-B_Cu.gbr, digital_inputs-B_Mask.gbr, digital_inputs-B_Paste.gbr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]
2022-10-03 CAN power
    [digital_inputs.kicad_sch]
2023-05-02 #14 #15
    [digital_inputs.kicad_pcb, digital_inputs.kicad_sch]
2023-07-27 #3 #14 #16 #11 #17
    [digital_inputs.kicad_pcb, digital_inputs.kicad_sch]
2023-07-28 #16 #17
    [digital_inputs.kicad_sch]
2023-08-01 Трассированная плата + файл замены U11
    [digital_inputs.kicad_pcb, digital_inputs.kicad_sch]
2023-08-02 [skip actions] Auto-generated board
    [digital_inputs-B_Cu.gbl, digital_inputs-B_Mask.gbs, digital_inputs-B_Paste.gbp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]
2023-08-02 more automation
    [bom_replace_digital_inputs-a.csv]
2023-08-02 Upd pcb
    [digital_inputs.kicad_pcb, digital_inputs.kicad_sch]
2023-08-02 #14 #16 #23
    [digital_inputs.kicad_pcb, digital_inputs.kicad_sch]
2023-08-02 Fix empty board suffix https://github.com/andreika-git/hellen-one/issues/318
2023-08-08 Drill fix
    [digital_inputs.kicad_pcb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]
2023-08-08 Remove boards
    [inputs-BOM.csv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]
2023-08-08 Remove old gerbers
    [digital_inputs-B_Cu.gbl, digital_inputs-B_Cu.gbr, digital_inputs-B_Mask.gbr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]
2023-08-08 Run create-board
2023-08-09 JLCPCB Part #
    [digital_inputs.kicad_sch]
2023-08-09 JLC shortage fix
    [bom_replace_digital_inputs-a.csv]
2023-08-10 Replace opamp
    [bom_replace_digital_inputs-a.csv, digital_inputs.kicad_pcb, digital_inputs.kicad_sch]
2023-08-21 #31 #26 #32 #33 #30
    [digital_inputs.kicad_pcb, digital_inputs.kicad_sch]
2023-10-30 #29 #39 #40
    [digital_inputs.kicad_pcb, digital_inputs.kicad_sch]
2024-01-04 Fix #41
    [digital_inputs.kicad_pcb, digital_inputs.kicad_sch]
2024-01-04 [skip actions] Auto-generated board v2.1
    [digital_inputs-B_Cu.gbl, digital_inputs-B_Mask.gbs, digital_inputs-B_Paste.gbp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]
2024-01-05 Fix #42
    [bom_replace_digital_inputs-c.csv]
2024-10-19 Rev D export
    [bom_replace_digital_inputs-d.csv, digital_inputs.kicad_pcb, digital_inputs.kicad_sch]
2024-10-19 moving everything
    [bom_replace_digital_inputs-a.csv, bom_replace_digital_inputs-c.csv, bom_replace_digital_inputs-d.csv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]
2024-10-19 old and dead
    [digital_inputs-c-BOM-JLC.csv, digital_inputs-c-BOM.csv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]
2024-10-19 moving archive
    [digital_inputs-a-BOM-JLC.csv, digital_inputs-a-BOM.csv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]
2025-04-13 new version
    [BottomPiece-TestRig.stl, IWS Bottom Case.stl, IWS Top Case.stl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]
